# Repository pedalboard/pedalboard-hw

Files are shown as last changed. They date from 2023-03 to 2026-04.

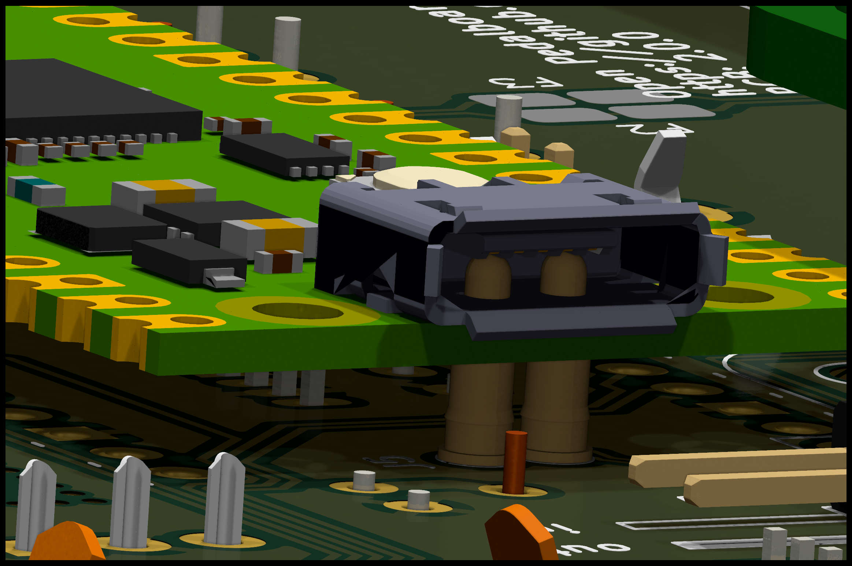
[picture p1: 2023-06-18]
img/pico-usb.png

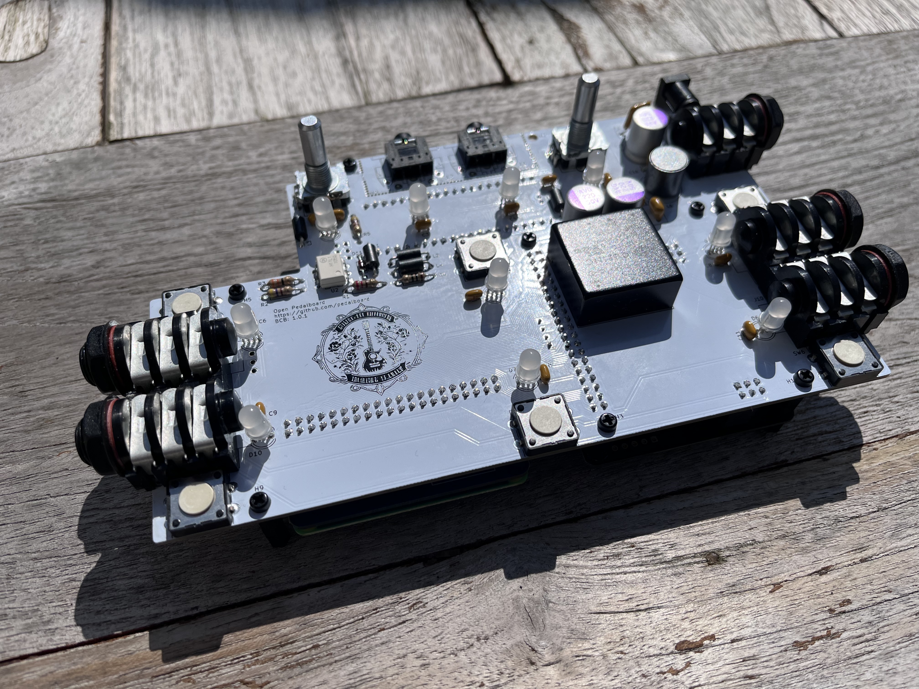
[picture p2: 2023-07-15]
img/prototype.jpeg

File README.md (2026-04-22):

# Open Pedalboard Mainboard

Mainboard for processing audio and/or MIDI data on a pedalboard.

**[Documentation →](https://pedalboard.github.io/pedalboard-hw/latest/)**

PCB 3D Render

## Design Goals

- Modular: MIDI-only or combined MIDI + audio
- Raspberry Pi CM4/CM5 for audio processing (< 2ms latency)
- RP-2040 MIDI controller with independent firmware
- Maker friendly: common components, existing modules
- Flat design: 30mm case height target

## Links

- [Interactive schematic & PCB viewer](https://pedalboard.github.io/pedalboard-hw/latest/board/)
- [Interactive BOM](https://pedalboard.github.io/pedalboard-hw/latest/board/)
- [Downloads & releases](https://pedalboard.github.io/pedalboard-hw/latest/release/)
- [Digi-Key shared list](https://www.digikey.ch/de/mylists/list/DJ3I9KG222)
- [PCBWay manufacturing](https://www.pcbway.com/project/shareproject/Open_Source_Pedalboard_Platform_8e065d23.html)
- [Mechanical parts (3D printable)](https://github.com/pedalboard/pedalboard-case)
- [Release procedure](doc/release-procedure.md)

## License



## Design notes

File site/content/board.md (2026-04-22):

---
title: Board
type: board
weight: 20
---

## Audio Processing

- Raspberry Pi [Compute Module 4](https://www.raspberrypi.com/products/compute-module-4/) or [Compute Module 5](https://www.raspberrypi.com/products/compute-module-5/)
  - Flexible memory options for cost optimisation
  - Optional WiFi
  - Very low latency (~2ms with [ELK Audio OS](https://www.elk.audio/how-elk-audio-os-works))
- [Pedalboard Soundcard](https://pedalboard.github.io/pedalboard-soundcard/latest/) — two channel differential I/O
- or HiFiBerry [DAC+ ADC PRO](https://www.hifiberry.com/shop/boards/hifiberry-dac-adc-pro/) — high quality stereo I/O
- USB-A host + Mini USB device mode (firmware update)

## MIDI and Control Surface

- Raspberry [RP-2040](https://datasheets.raspberrypi.com/rp2040/rp2040-datasheet.pdf) with custom [firmware](https://github.com/pedalboard/pedalboard-midi) (USB or WLAN update)
- 6 foot buttons (push, release, long/short press)
- 2 rotary encoders with push button
- 2 expression pedal inputs
- 8 [RGB LED rings](https://github.com/pedalboard/pedalboard-led-ring) around each foot button
- 2 RGB status LEDs
- STEMMA I2C connector for 2 OLED displays
- I2C EEPROM for config storage
- Flexible MIDI I/O: DIN 5, 3.5mm TRS, header pins, USB MIDI

## Power Supply

- 6–28V DC input (standard pedalboard PSU) with 3A buck converter
- USB powered option for MIDI module
- ORing support between onboard PSU and USB power

## Design Decisions

- **USB 2.0 only** — 480 Mbps is more than sufficient for audio (stereo 24-bit/192kHz ≈ 9 Mbps) and MIDI. USB 3.0 would add cost, routing complexity, and require a 4-layer PCB — with no practical benefit for this use case.
- **2-layer PCB** — keeps manufacturing cost low and the project accessible to makers. USB 2.0 signal integrity is manageable on 2 layers with careful routing and short trace lengths.
- **Dual-processor architecture** — the RP2040 handles MIDI control with instant startup, while the CM4/CM5 runs ELK Audio OS for audio processing. This separation ensures the control surface is always responsive, independent of the audio OS boot state.
- **Modular design** — the board works as a standalone MIDI controller without a CM4 installed, or as a full audio processing platform with CM4/CM5 + soundcard. Common components and existing modules (HiFiBerry, CM4) keep the BOM accessible.

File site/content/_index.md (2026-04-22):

---
title: Overview
weight: 10
---

PCB 3D Render

Mainboard for processing audio and/or MIDI data on a pedalboard.
Modular design supporting MIDI-only or combined MIDI + audio configurations.

## Key Features

- Raspberry Pi CM4/CM5 for audio processing (< 2ms latency with ELK Audio OS)
- RP-2040 MIDI controller with independent firmware and instant startup
- 6 foot buttons (short/long press, push/release) + 2 rotary encoders
- 8 RGB LED ring connectors + 2 OLED display ports
- Flexible MIDI I/O: DIN 5, 3.5mm TRS, USB MIDI, header pins
- 2 expression pedal inputs
- USB-A host + Mini USB device (firmware update)
- 6–28V DC input with 3A buck converter, or USB powered

## Related

- [Sound Card](https://pedalboard.github.io/pedalboard-soundcard/latest/) — I²S audio codec HAT
- [Display Board](https://pedalboard.github.io/pedalboard-display/latest/) — LED rings and OLED displays

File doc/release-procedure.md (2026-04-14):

# How to create a release

The release procedure is not yet fully automated. Please follow below steps:

1. Bump Version

- In Schematic Editor: File -> Page Settings -> Update Issue Date and Revision
  (with export to other sheets)
- In PCB Editor: File -> Page Settings -> Update Issue Date and Revision
- Update CHANGELOG.md (release date)
- Update README.md
  - link the versioned docs.

  ```sh
  sed -i 's#/latest#/vX.Y.Z#g' README.md
  ```

  - link to a (optionally new) DigiKey revision

1. Create a Tag and push it.

   ```sh
   git tag vX.Y.Z
   git push origin vX.Y.Z
   ```

   This triggers the CI to deploy versioned docs to
   `pedalboard.github.io/pedalboard-hw/vX.Y.Z/`.

1. Create a release.

- Generate Release Notes
- Add the relevant content from CHANGELOG.md
- Download the generated_output.zip file from the tagged Action run.
- Add the version to generated_output-x.y.z.zip
- Upload the zip as artifact of the release

1. Bump the version on main to RC1 (as described above)

- Change old version for diff on pedalboard-hw.kibot.yaml (2 lines!)
- Add a new Release in CHANGELOG.md

  ```sh
  sed -i 's#/vX.Y.Z#/latest#g' README.md
  ```

1. Update the OSHWA registration (../../oshwa/README.md)

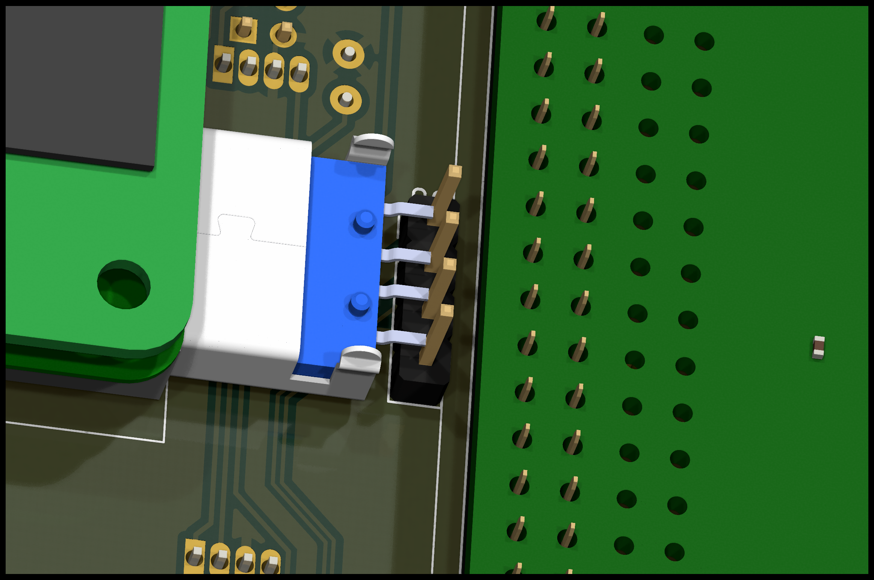
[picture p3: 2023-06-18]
img/cm4-usb.png

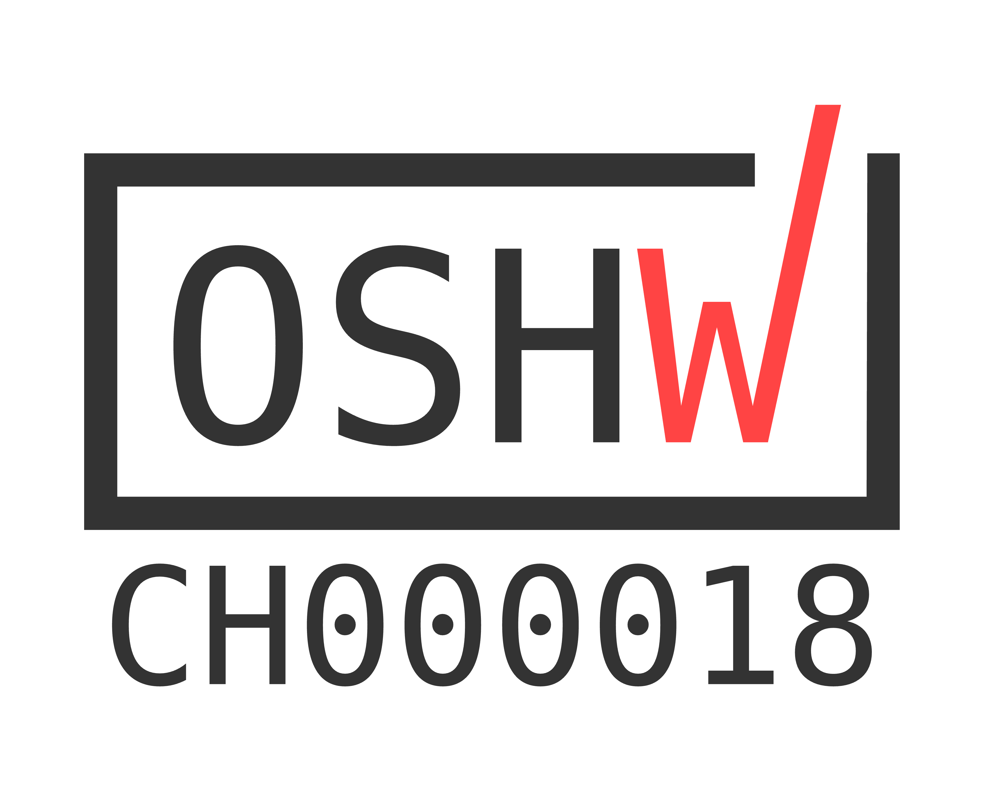
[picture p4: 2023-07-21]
img/certification-mark-CH000018-stacked.png

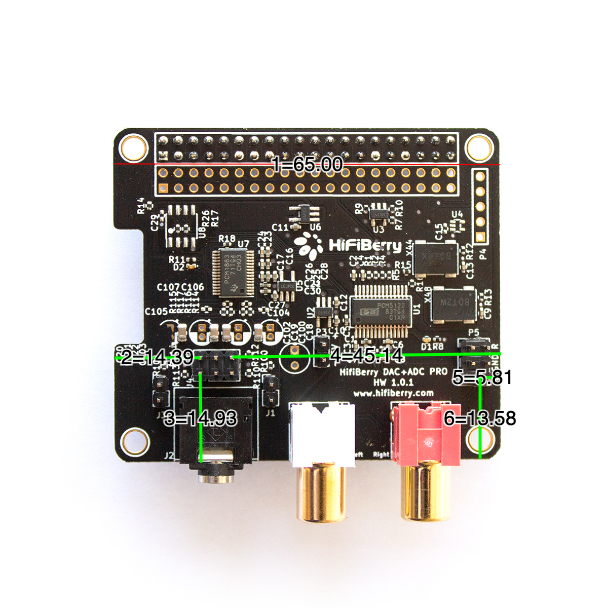
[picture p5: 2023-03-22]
img/dac-adc.png

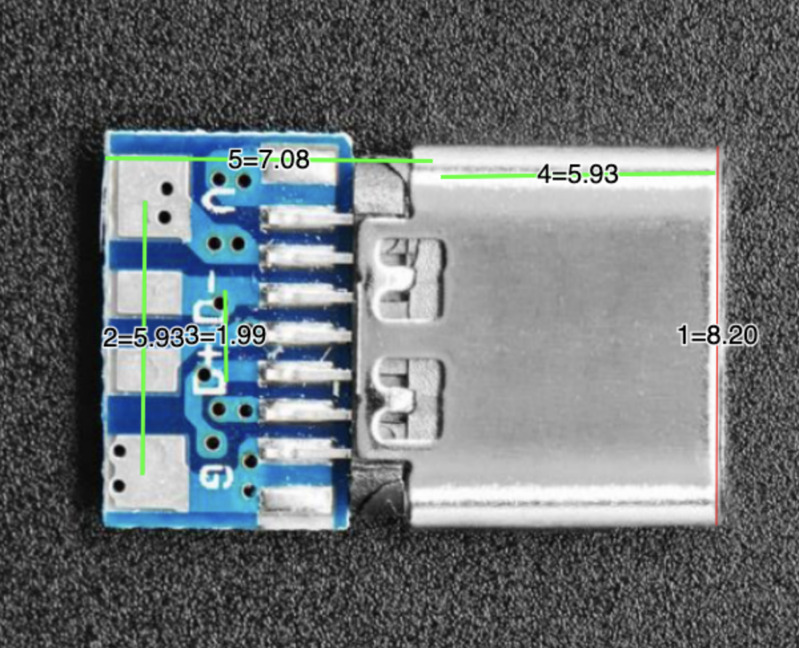
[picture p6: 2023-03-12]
img/usb-c.png

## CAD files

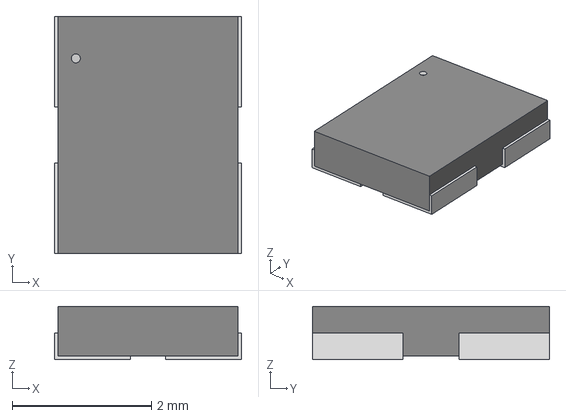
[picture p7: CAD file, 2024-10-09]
3d-models/ABM8-272-T3_ABR.step
2.69 x 3.40 x 0.765 mm

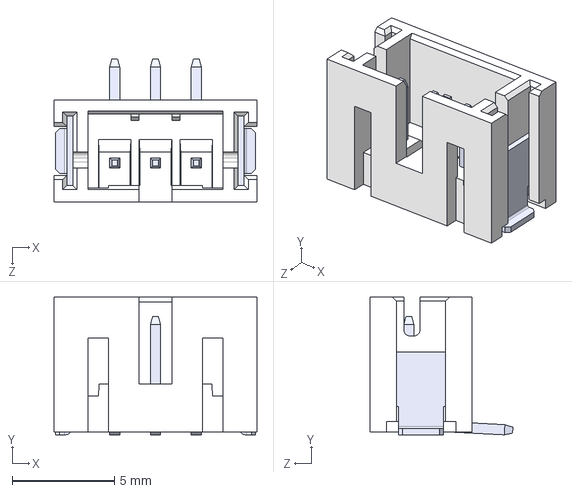
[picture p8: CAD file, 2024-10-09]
3d-models/B3B-PH-SM4-TB(LF)(SN)--3DModel-STEP-269445.STEP
9.95 x 6.75 x 7.00 mm

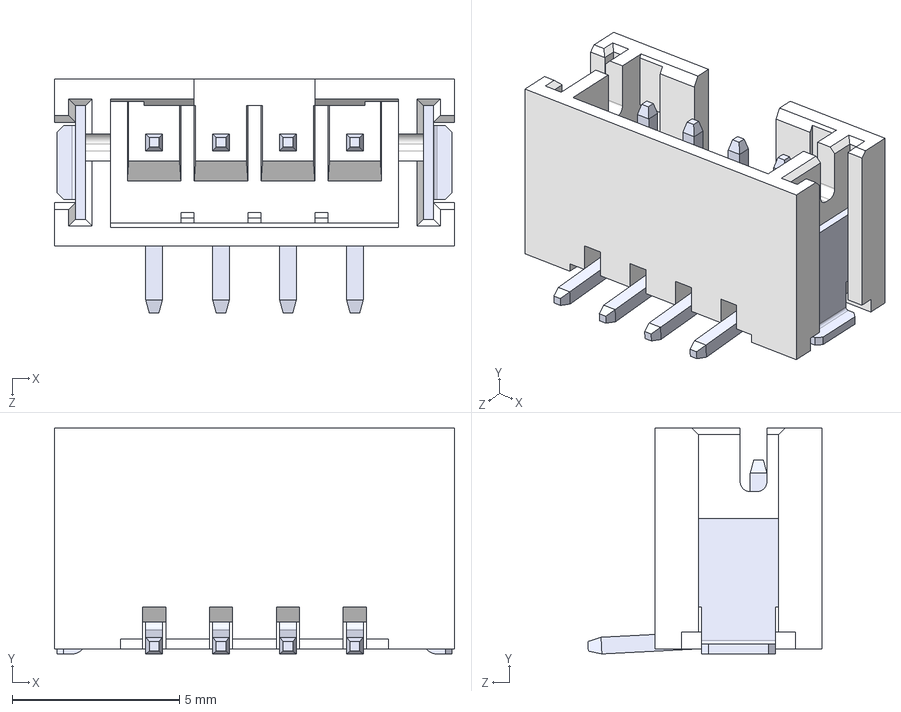
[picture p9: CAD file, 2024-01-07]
3d-models/B4B-PH-SM4-TB (LF)(SN).STEP
12.0 x 6.75 x 7.00 mm

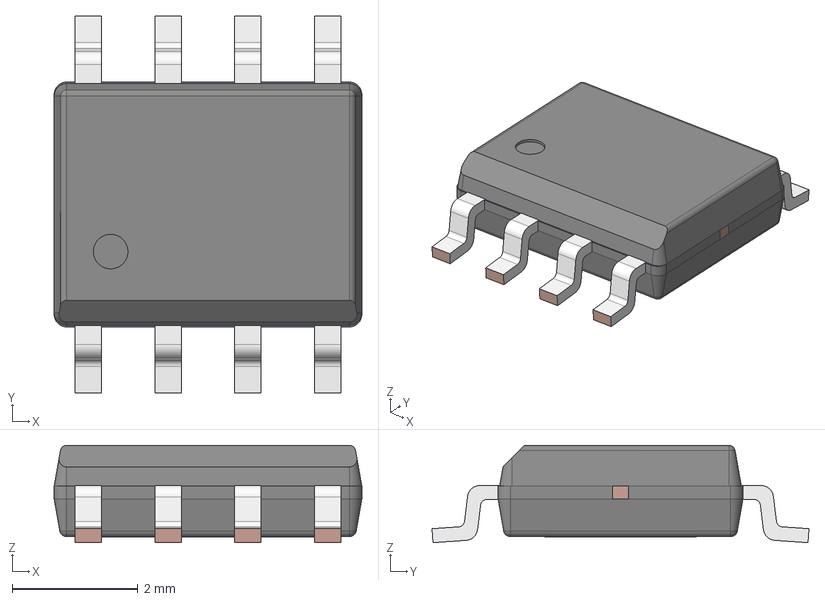
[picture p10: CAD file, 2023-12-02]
3d-models/SO-8EP.STP
4.90 x 6.00 x 1.55 mm
CPD
LDF - outer lead
LDF - 8L-EP

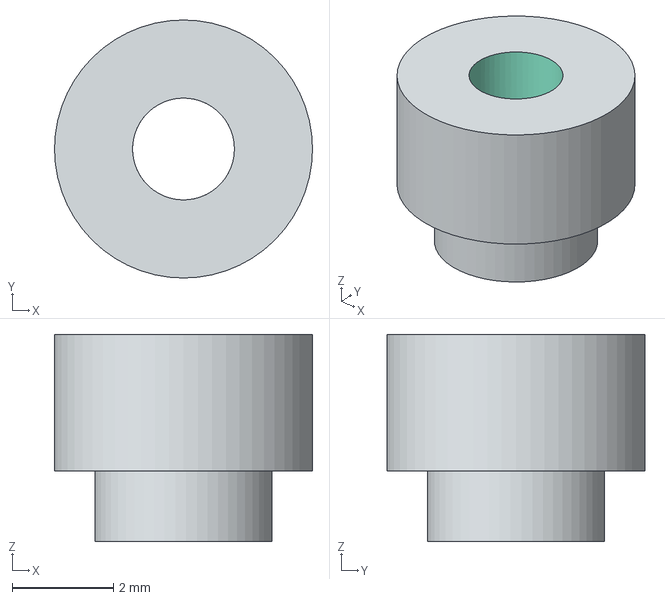
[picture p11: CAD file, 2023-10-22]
3d-models/spacer.stp
5.10 x 5.10 x 4.10 mm

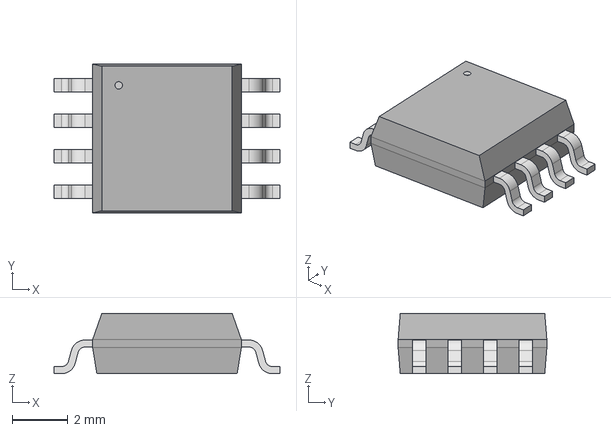
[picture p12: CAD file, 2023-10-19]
3d-models/SOIC_128JVSIQ_WIN.step
8.10 x 5.33 x 2.16 mm

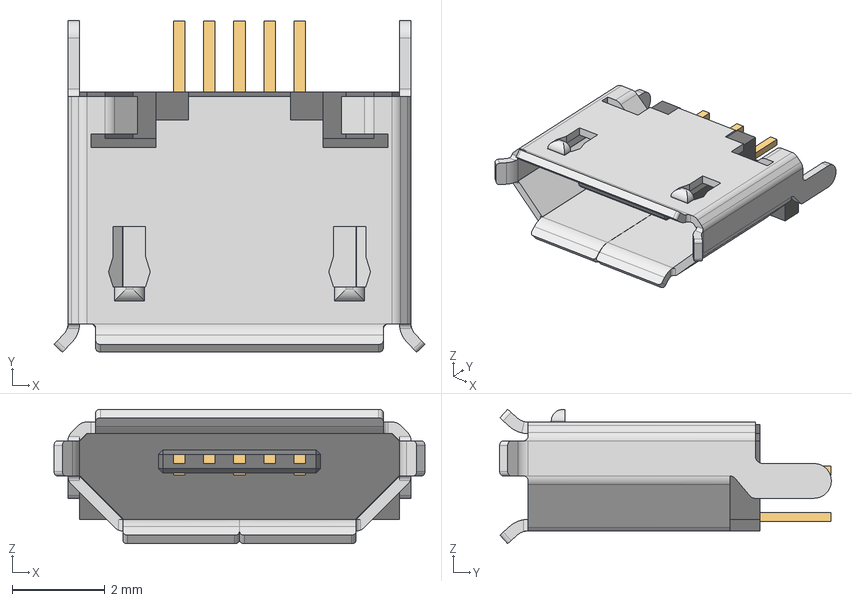
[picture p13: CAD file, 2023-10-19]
3d-models/USB_Micro-B_Wuerth_614105150721.step
8.00 x 7.15 x 2.90 mm
614105150721_Housing
614105150721_Pin1 x 3
614105150721_Pin2 x 2
614105150721_Shielding

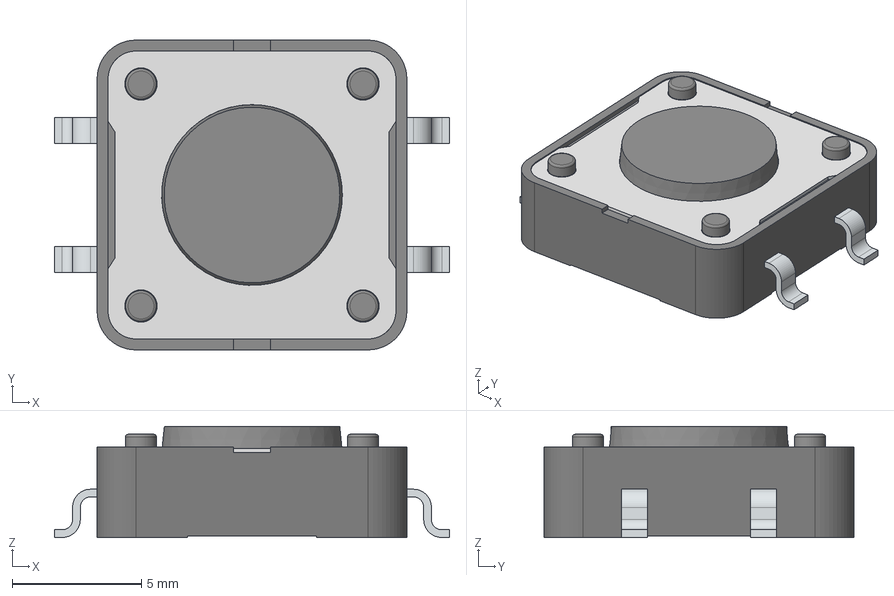
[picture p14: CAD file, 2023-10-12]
3d-models/WE-tact-button.stp
15.3 x 12.0 x 4.30 mm
Contactplates
Stem
Cover
Contact Plate
Frame
Terminal

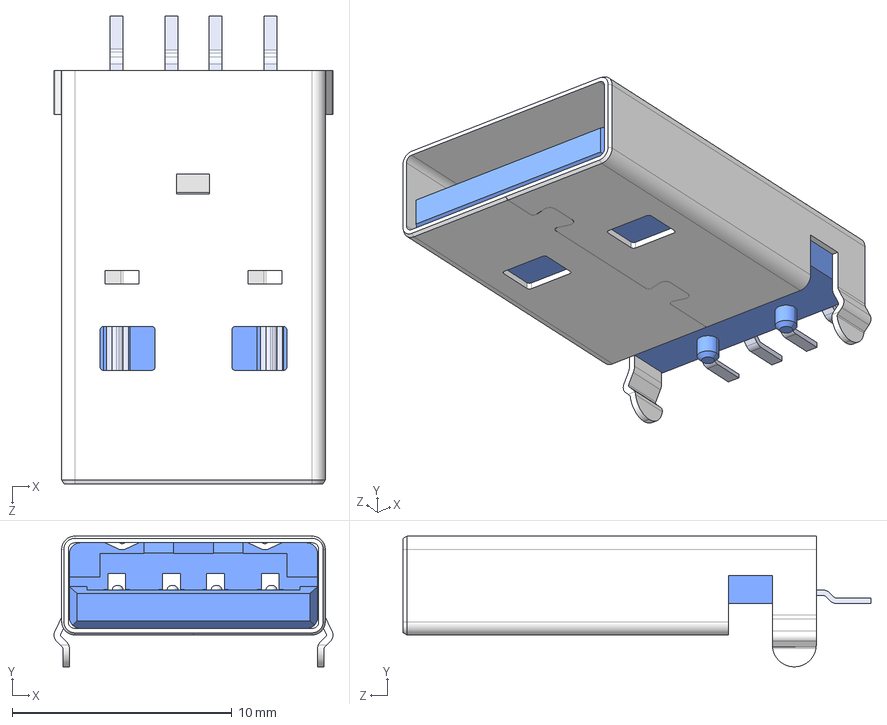
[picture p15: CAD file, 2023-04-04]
3d-models/USB1061-GF-L-A.stp
12.7 x 5.95 x 21.3 mm
USB1061-GF-L-A_PART5
USB1061-GF-L-A_PART4
USB1061-GF-L-A_PART3
USB1061-GF-L-A_PART2
USB1061-GF-L-A_PART1

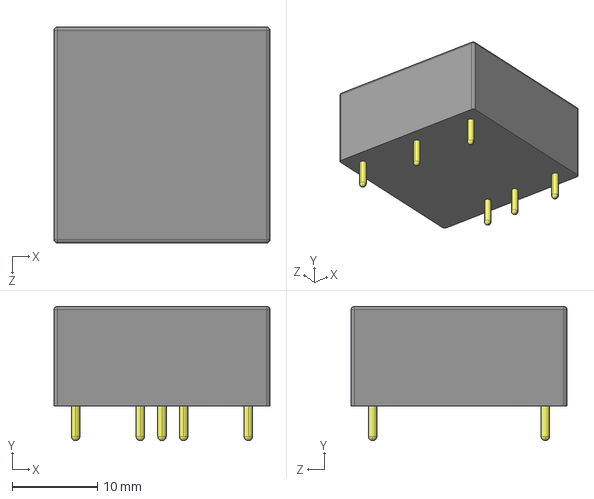
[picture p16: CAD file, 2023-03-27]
3d-models/PDQE15-Q24-S5-D.step
25.4 x 15.8 x 25.4 mm

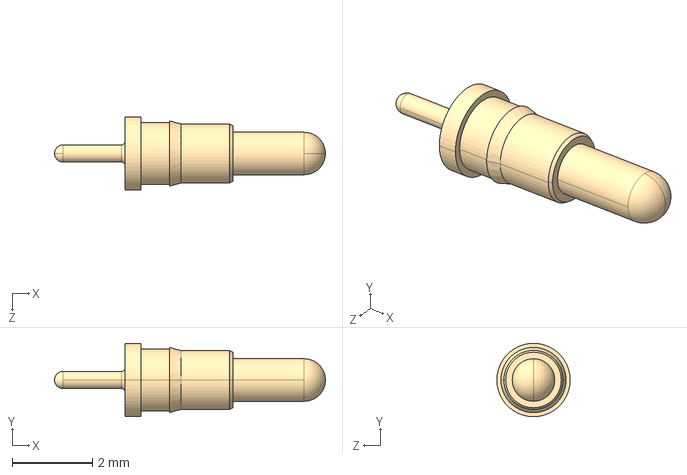
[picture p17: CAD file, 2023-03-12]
3d-models/mill-max-0906-2-15-20-75-14-11-0.step
6.76 x 1.83 x 1.83 mm

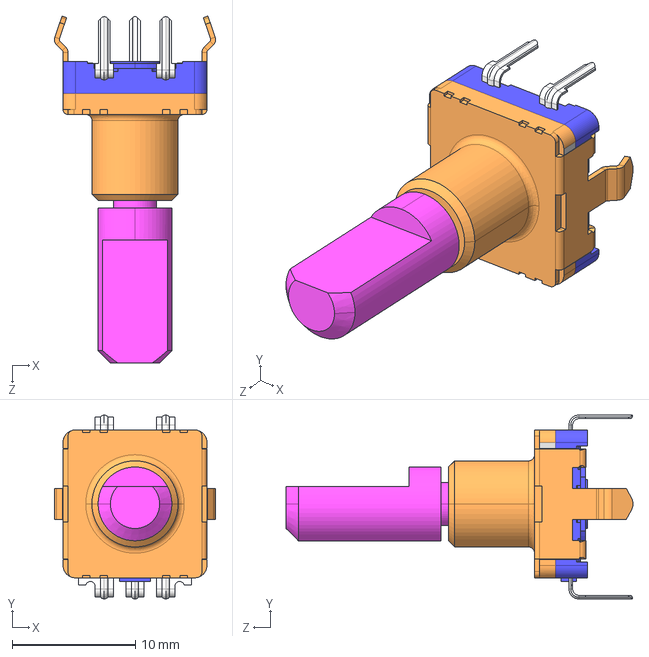
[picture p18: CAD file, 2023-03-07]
3d-models/EC11E-05SW.STEP
13.1 x 15.0 x 28.2 mm

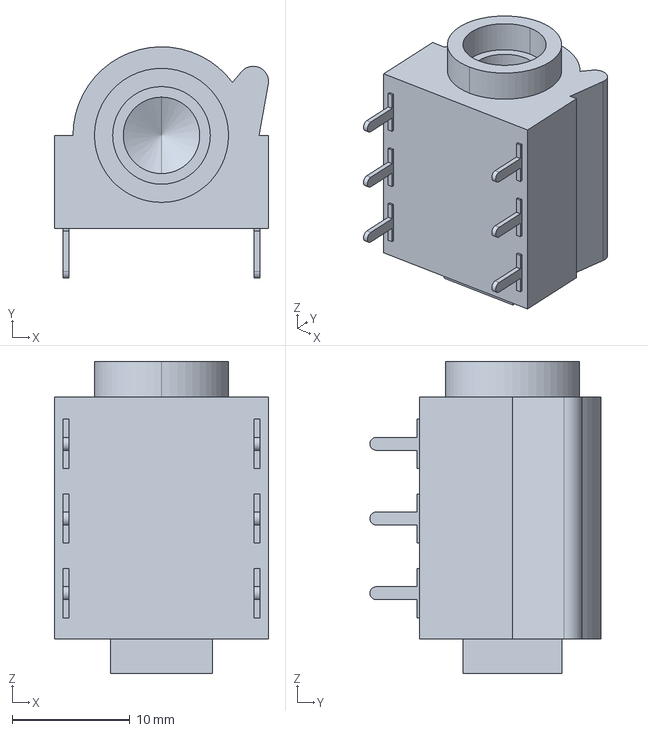
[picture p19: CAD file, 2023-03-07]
3d-models/3-D NMJ6HCD2.stp
18.2 x 19.7 x 26.5 mm

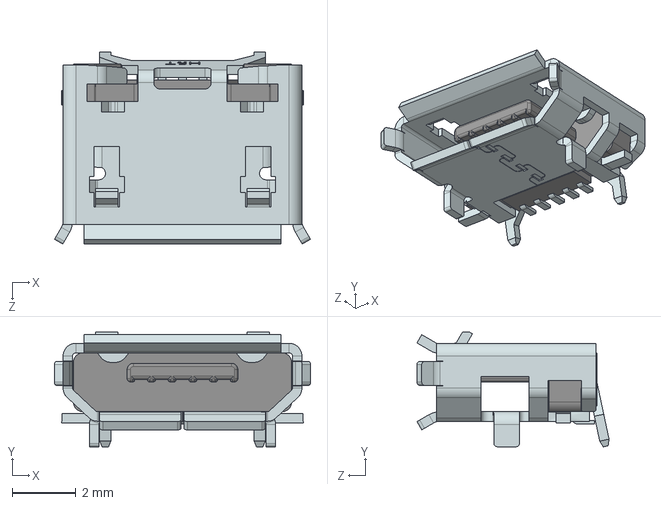
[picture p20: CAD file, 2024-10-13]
3d-models/10103594-0001LF--3DModel-STEP-269445.STEP
8.04 x 3.60 x 6.03 mm

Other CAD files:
3d-models/694106301002 (rev1).stp

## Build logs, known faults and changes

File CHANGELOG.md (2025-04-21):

# Change Log

## TODO

- 2nd USB out
- Input protection
- Bypass USB for MIDI-only controller
- SMD Debug connectors (angled)
- Consistent clearance around mounting holes
- Larger (cheaper) EEPROM

## 4.0.1-RC - -

- Upgrade to KiCad 9
- Tested with CM5

## 4.0.0 - Pedalboard Display and USB - 2024.10.16

### Added

- USB Device in and USB out
- OSHW Symbol
- Silkscreen text for reset/boot switches
- Silkscreen text for MIDI controller inputs
- Git revision is added to schematics and PCB
- Pull-up resistors for I2C bus
- Two more mounting holes (for development)
- 3D model for JST (Stemma)
- One more mounting hole in the center
- User (Test) LED on RP2040
- EEPROM for storing configuration

## Changed

- Change title to Open Pedalboard Mainboard
- Use "knowout" text style for better visibility of connectors
- Swap power symbol to better reflect the terminal connector
- Replace HiFi Berry by pedalboard-soundcard
- Upgrade to KiCad 8
- use smaller XTAL ABM8-272-T3

## Removed

- Fiducials and holes from BOM
- Direct USB connection to RP2040
- LEDs are removed (only 5V adapter left) in favour of the pedalboard-display

## [3.1.1] - Cost Optimisation:  Bug Fixes - 2023-12-05

### Changed

- Increase min. through hole size to 0.3mm

## [3.1.0] - Cost Optimisation:  Bug Fixes - 2023-12-04

### Added

- Stemma connector for displays
- Switch for boot mode and reset of RP2040
- 2 more LED rings for rotary encoders

### Changed

- Increase activity LED resistor to reduce brigtness
- Stemma compatibility for LED out
- Smaller JST PH connectors for MIDI IN/OUT

### Fixed

- Fix USB boot mode bug (wrong wiring)
- Fix CM4 Power LED (invert logic)
- Use power supply based on CM4 IO Board V5
- Decrease stencil sizes (10%) for RP2040- and CM4 connector pads

## [3.0.1] - Cost optimization: Prototype Production Release - 2023-10-20

### Changed

- Increase slot size to (restriction of PCBway)

## [3.0.0] - Cost optimization - 2023-10-19

### Changed

- Use SMD components for MIDI I/O
- Use SMD actuator buttons
- Use concrete PSU implemented with SMD components.
- Use MOS FET instead of diode for reverse polarity protection.
- Use official solder jumper instead of homegrown PCB fuses.
- Increase size of PCB and use 5V zone around the edges.
- Use Connector_JST (XH) for MIDI and LED Ext.
- Directly interface CM4 (Remove CM4 Nano carrier)
- Replace the Pico by directly use RP2040

### Added

- Compatibility with the [Hammond Manufacturing 1590DD](https://www.hammfg.com/files/parts/pdf/1590DD.pdf) case.
- Additional analog (EXP 2) input
- Fidcuials for PnP
- Alternative screw terminal for power input

## [2.1.0] - LED rings - 2023-08-09

### Added

- [Pedalboard LED Ring](https://github.com/pedalboard/pedalboard-led-ring) added.

### Changed

- Use of [SMD Spacers](https://www.digikey.ch/de/products/detail/w%C3%BCrth-elektronik/9774027151R/5320625)
  under the foot buttons for improved mechanical stability.
- The power supply for LEDs from 3.3V to 5V. Allows the use of much larger LED matrices.
- Therefore, a level shifter from 3.3V to 5V had to be added.

## [2.0.0] - 2023-04-24

### Added

- Silkscreen information for connectors to avoid having to refer to the schematics
- Reverse power protection circuit added to Power input.
- Power Raspberry Pico from 5V power supply
- Add internal MIDI connection to free up USB.

### Changed

- BOM: Change LEDs which support 3.3V
- Swap SW A with SW D to cleanup connections

### Fixed

## [1.0.2] - 2023-04-04

### Fixed

- Fix the USB connection between Raspberry Pi and Pico

## [1.0.1] - 2023-03-27

First manufactured version

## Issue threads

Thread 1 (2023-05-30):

Support for LED ring

laenzlinger, 2023-05-30:
The https://github.com/pedalboard/pedalboard-led-ring project provides a nice ring around the foot buttons instead of simple LED.

The protocol is very similar to the single LED but in addition a power supply line needs to be routed and additional pin header are required.

laenzlinger, 2023-06-09:
The routing is already mostly done.

The mounting holes also need to be refactored as a result of the changes now
In addition some sort of 3.3 to 5V adaptation is required since the LED rings are now powered by 5V

laenzlinger, 2023-09-10:
added missing line adapter and spacers. I consider this as done now

Closed 2023-09-10.

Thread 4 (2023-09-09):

LCD support

laenzlinger, 2023-09-09:
Add one?, two? or three? LCDs
Or maybe even 6?

laenzlinger, 2023-12-04:
On V3 i have added a STEMMA output to support small I2C displays

laenzlinger, 2024-01-07:
added pull-up resistors to make it more versatile

laenzlinger, 2024-10-13:
on V4 the displays are on a separate PCB where also all the LED rings are contained.
Two 1.5" 128x128 pixel screens were added.

Closed 2025-04-21.

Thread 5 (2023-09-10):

Fix documentation versioning

laenzlinger, 2023-09-10:
currently the docs are not not avialable for old versions.

laenzlinger, 2023-09-10:
also the release procedure is not yet well documented

laenzlinger, 2023-09-10:
- copied all the released versions into a subdirectory
- the main is pushing into latest

laenzlinger, 2023-09-10:
we should add a version switch to the header if possible

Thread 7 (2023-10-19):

pedalboard soundcard

laenzlinger, 2023-10-19:
Better output drivers (currently the DAC output of the HiFi Berry board are used)
* survive 48V phantom power on output
* Differential outputs (e.g. https://thatcorp.com/datashts/THAT_1606-1646_Datasheet.pdf)
* Output stage https://www.amb.org/audio/
Better input protection

laenzlinger, 2023-12-05:
check out this: https://github.com/zynthian/zynthian-hw/tree/master/ZynADAC

laenzlinger, 2023-12-31:
Implementation ongoing https://github.com/pedalboard/pedalboard-soundcard

laenzlinger, 2024-10-14:
supported on V4

Closed 2025-04-21.

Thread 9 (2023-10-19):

EPROM storage for settings.

laenzlinger, 2023-10-19:

laenzlinger, 2024-01-07:
is it really needed, can't we just store the it in the flash memory?

laenzlinger, 2024-10-14:
added it on PCB, I2C is so small and enough space available

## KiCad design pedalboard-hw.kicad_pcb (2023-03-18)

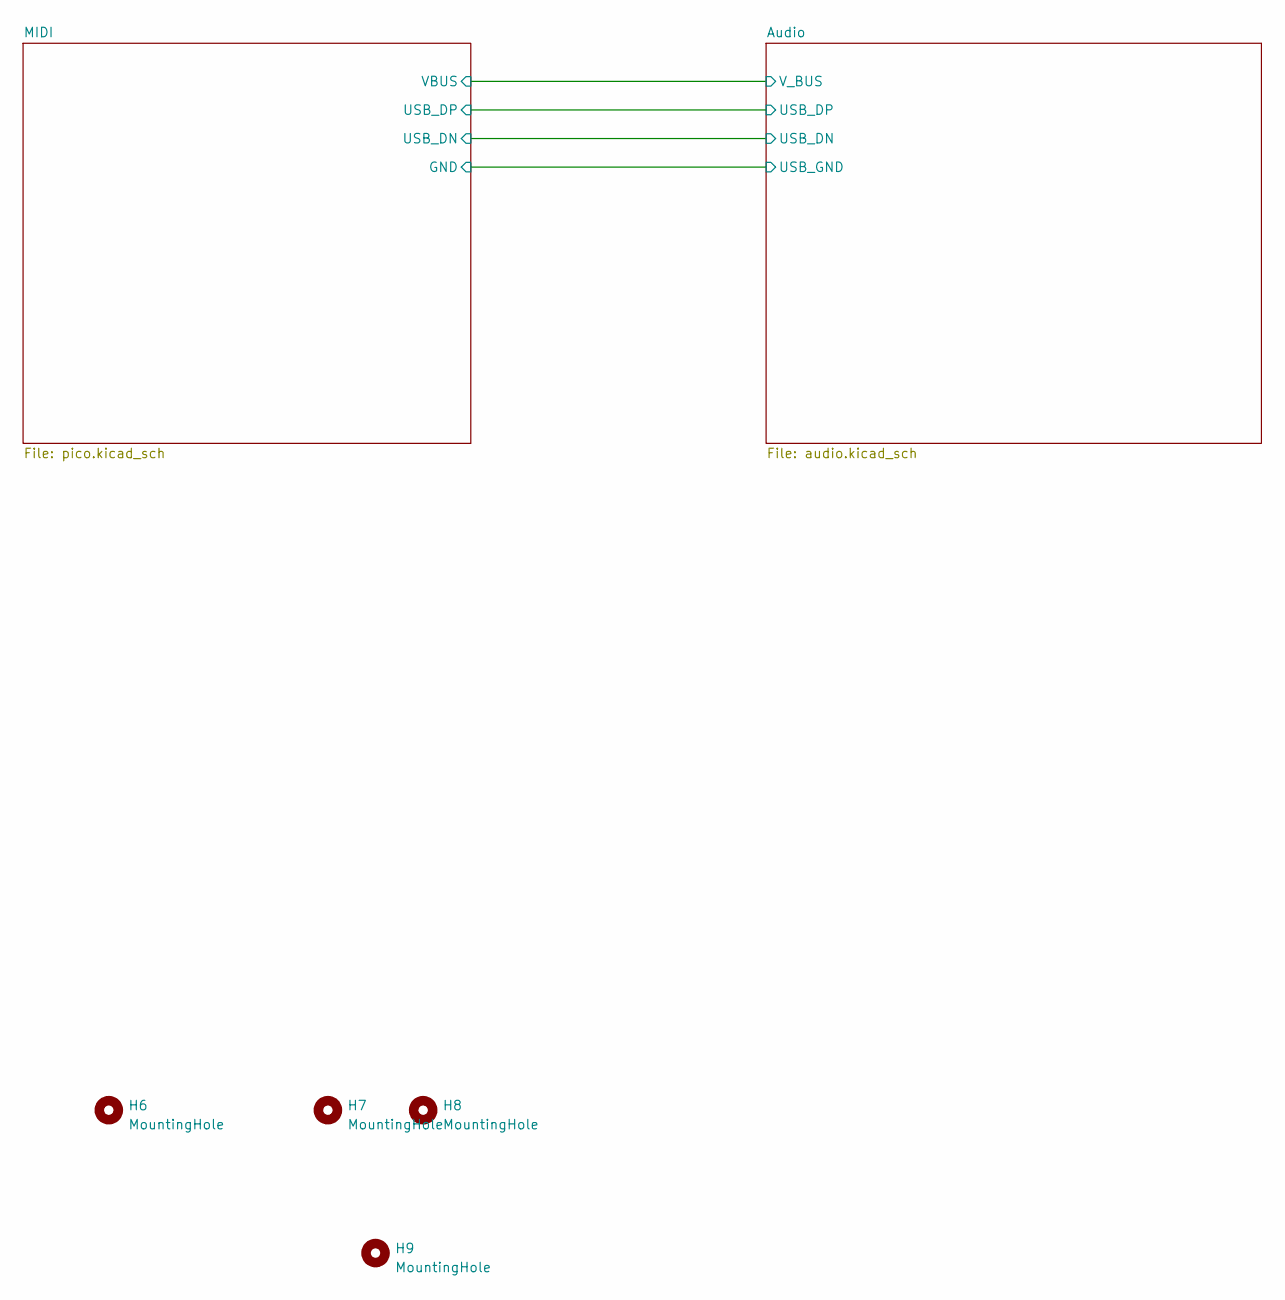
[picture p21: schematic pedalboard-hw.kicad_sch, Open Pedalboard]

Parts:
H6, H7, H8, H9: MountingHole; MountingHole_2.7mm_M2.5_DIN965

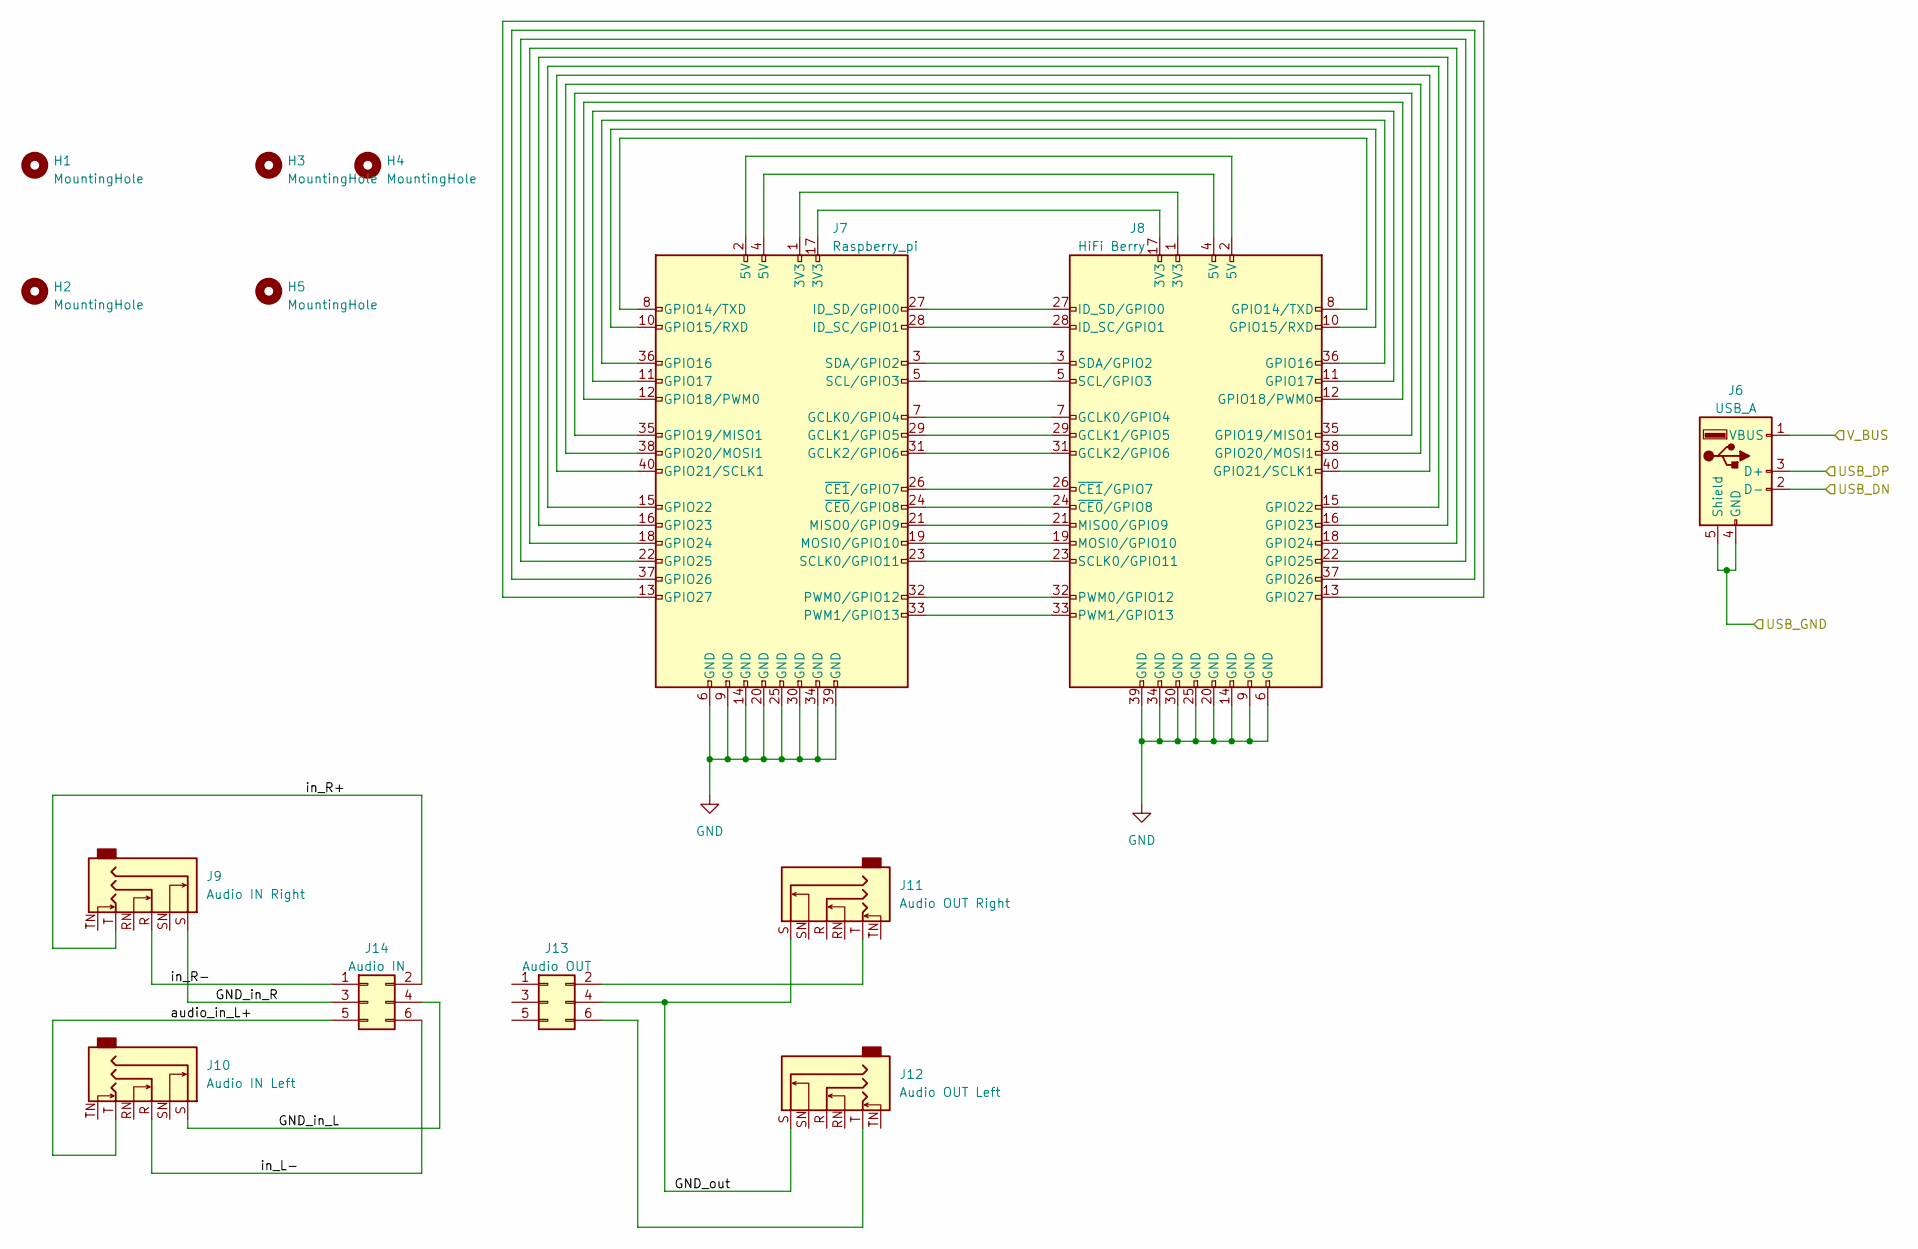
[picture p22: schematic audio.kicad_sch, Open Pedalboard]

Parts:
H1, H2, H3, H4, H5: MountingHole; MountingHole_2.7mm_M2.5_DIN965
J6: USB_A; USB A BCB Male Plug
J7: Raspberry_pi; Raspberry PI Compute Module CM4 Nano A
J8: HiFi Berry; HiFi Berry DAC ADC+
J9: Audio IN Right; Jack_6.35mm_Neutrik_NMJ6HCD2_Horizontal
J10: Audio IN Left; Jack_6.35mm_Neutrik_NMJ6HCD2_Horizontal
J11: Audio OUT Right; Jack_6.35mm_Neutrik_NMJ6HCD2_Horizontal
J12: Audio OUT Left; Jack_6.35mm_Neutrik_NMJ6HCD2_Horizontal
J13: Audio OUT; PinSocket_2x03_P2.54mm_Vertical
J14: Audio IN; PinSocket_2x03_P2.54mm_Vertical

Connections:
/Audio/GND_in_L: J10.S, J14.4
/Audio/GND_in_R: J9.S, J14.3
/Audio/GND_out: J11.S, J12.S, J13.4
/Audio/USB_DN: J6.2 (D-); also elsewhere on the board
/Audio/USB_DP: J6.3 (D+); also elsewhere on the board
/Audio/V_BUS: J6.1 (VBUS); also elsewhere on the board
/Audio/audio_in_L+: J10.T, J14.5
/Audio/in_L-: J10.R, J14.6
/Audio/in_R+: J9.T, J14.2
/Audio/in_R-: J9.R, J14.1
GND: J6.4 (GND), J6.5 (Shield), J7.6 (GND), J7.9 (GND), J7.14 (GND), J7.20 (GND), J7.25 (GND), J7.30 (GND), J7.34 (GND), J7.39 (GND), J8.6 (GND), J8.9 (GND), J8.14 (GND), J8.20 (GND), J8.25 (GND), J8.30 (GND), J8.34 (GND), J8.39 (GND); also elsewhere on the board
unnamed: J7.1 (3V3), J8.1 (3V3)
unnamed: J7.17 (3V3), J8.17 (3V3)
unnamed: J7.2 (5V), J8.2 (5V)
unnamed: J7.4 (5V), J8.4 (5V)
unnamed: J7.7 (GCLK0/GPIO4), J8.7 (GCLK0/GPIO4)
unnamed: J7.29 (GCLK1/GPIO5), J8.29 (GCLK1/GPIO5)
unnamed: J7.31 (GCLK2/GPIO6), J8.31 (GCLK2/GPIO6)
unnamed: J7.8 (GPIO14/TXD), J8.8 (GPIO14/TXD)
unnamed: J7.10 (GPIO15/RXD), J8.10 (GPIO15/RXD)
unnamed: J7.36 (GPIO16), J8.36 (GPIO16)
unnamed: J7.11 (GPIO17), J8.11 (GPIO17)
unnamed: J7.12 (GPIO18/PWM0), J8.12 (GPIO18/PWM0)
unnamed: J7.35 (GPIO19/MISO1), J8.35 (GPIO19/MISO1)
unnamed: J7.38 (GPIO20/MOSI1), J8.38 (GPIO20/MOSI1)
unnamed: J7.40 (GPIO21/SCLK1), J8.40 (GPIO21/SCLK1)
unnamed: J7.15 (GPIO22), J8.15 (GPIO22)
unnamed: J7.16 (GPIO23), J8.16 (GPIO23)
unnamed: J7.18 (GPIO24), J8.18 (GPIO24)
unnamed: J7.22 (GPIO25), J8.22 (GPIO25)
unnamed: J7.37 (GPIO26), J8.37 (GPIO26)
unnamed: J7.13 (GPIO27), J8.13 (GPIO27)
unnamed: J7.28 (ID_SC/GPIO1), J8.28 (ID_SC/GPIO1)
unnamed: J7.27 (ID_SD/GPIO0), J8.27 (ID_SD/GPIO0)
unnamed: J7.21 (MISO0/GPIO9), J8.21 (MISO0/GPIO9)
unnamed: J7.19 (MOSI0/GPIO10), J8.19 (MOSI0/GPIO10)
unnamed: J7.32 (PWM0/GPIO12), J8.32 (PWM0/GPIO12)
unnamed: J7.33 (PWM1/GPIO13), J8.33 (PWM1/GPIO13)
unnamed: J7.23 (SCLK0/GPIO11), J8.23 (SCLK0/GPIO11)
unnamed: J7.5 (SCL/GPIO3), J8.5 (SCL/GPIO3)
unnamed: J7.3 (SDA/GPIO2), J8.3 (SDA/GPIO2)
unnamed: J7.24 (~CE0/GPIO8), J8.24 (~CE0/GPIO8)
unnamed: J7.26 (~CE1/GPIO7), J8.26 (~CE1/GPIO7)
unnamed: J11.T, J13.2
unnamed: J12.T, J13.6

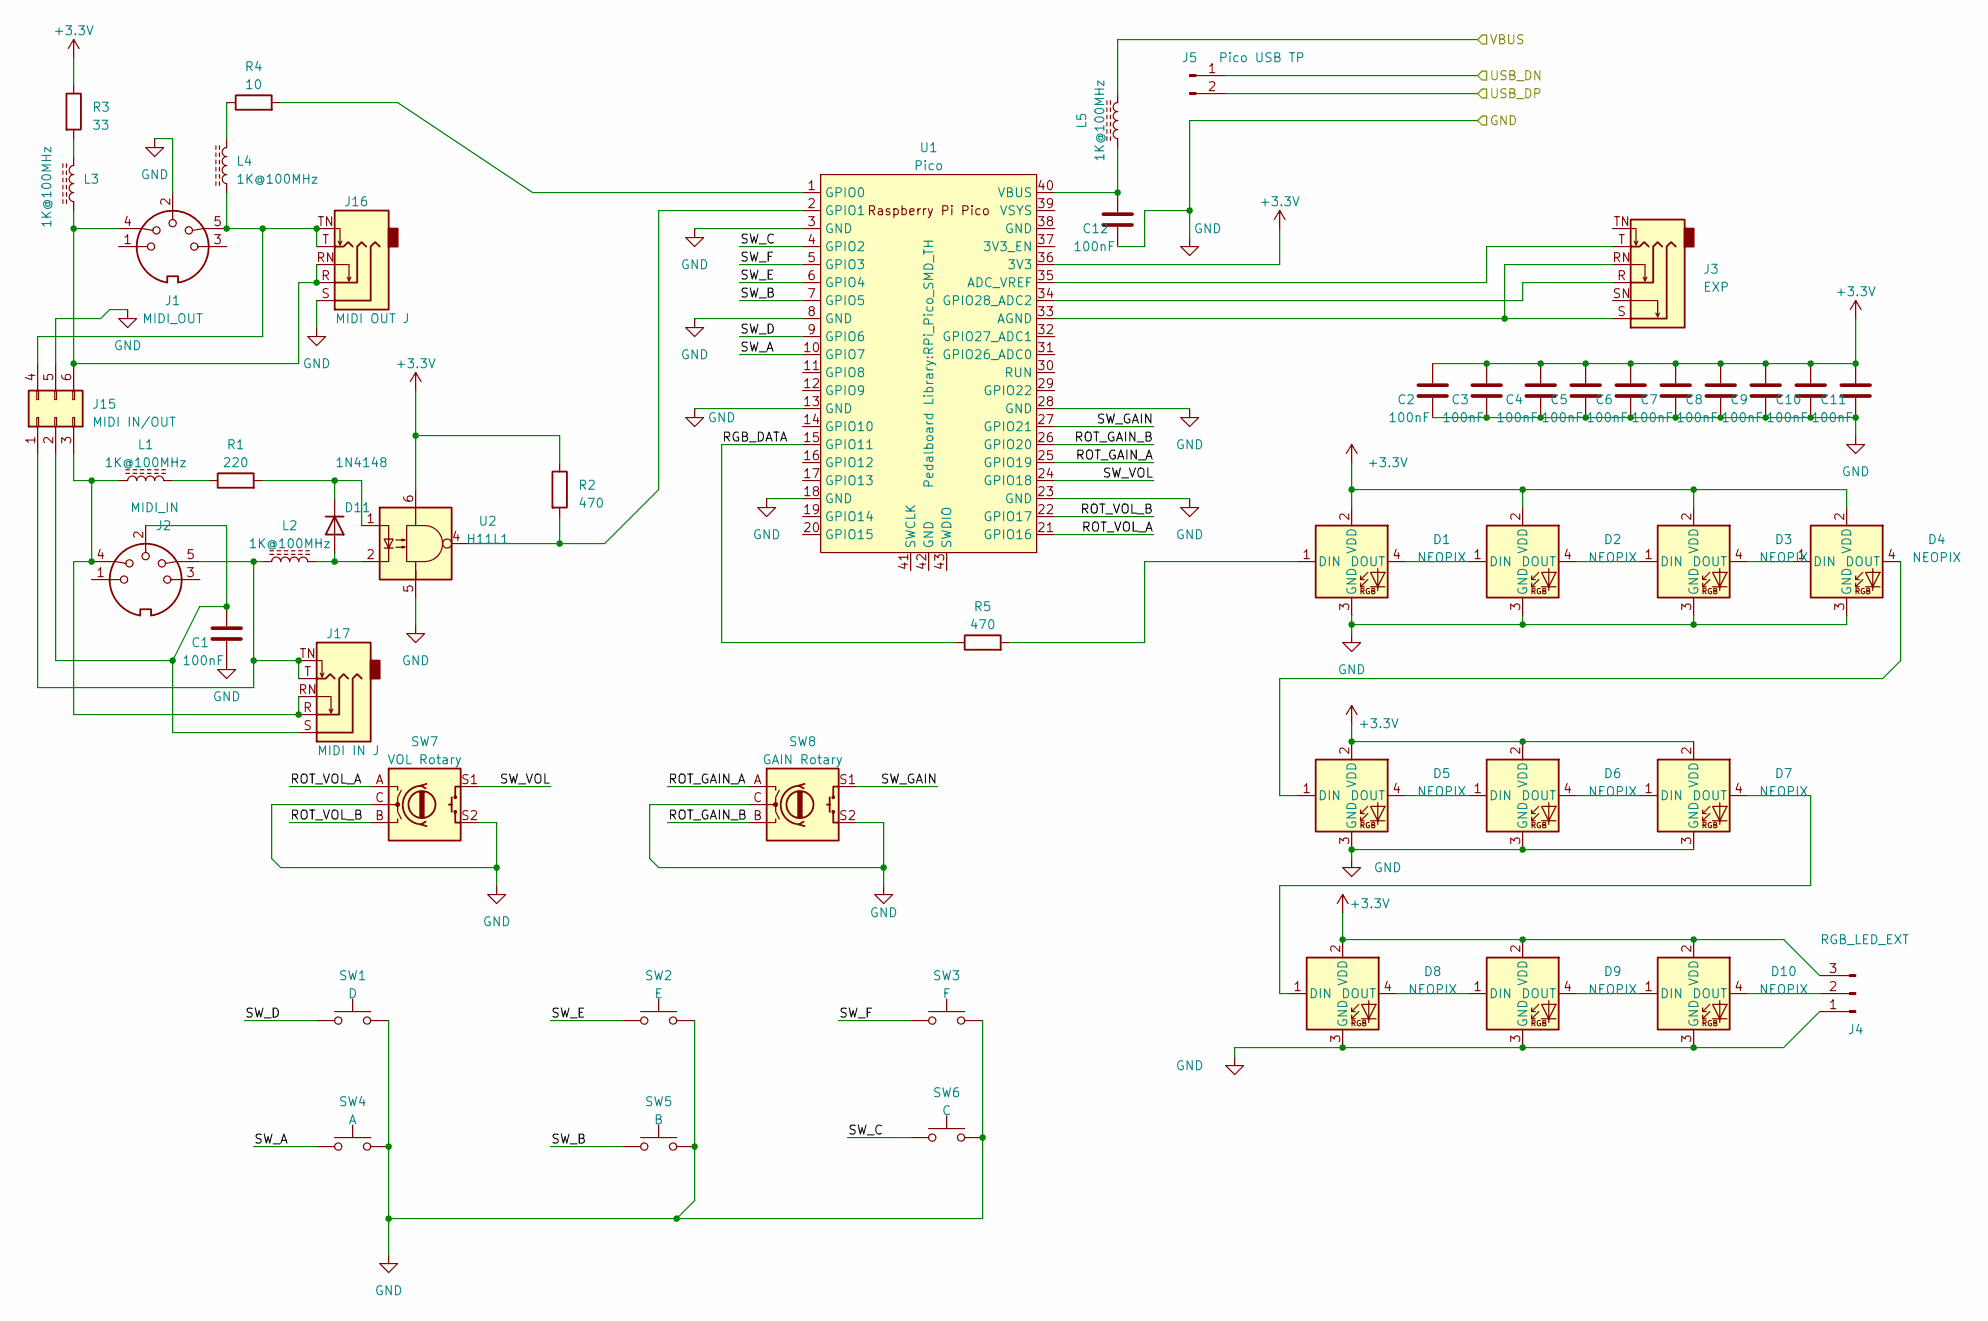
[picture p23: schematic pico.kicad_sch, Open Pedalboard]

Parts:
C1, C2, C3, C4, C5, C6, C7, C8, C9, C10, C11, C12: 100nF; C_Disc_D3.0mm_W1.6mm_P2.50mm
D1, D2, D3, D4, D5, D6, D7, D8, D9, D10: NEOPIX; LED_D5.0mm-NeoPixel
D11: 1N4148; D_DO-35_SOD27_P7.62mm_Horizontal
J1: MIDI_OUT; CP-2350
J2: MIDI_IN; CP-2350
J3: EXP; Jack_6.35mm_Neutrik_NMJ6HCD2_Horizontal
J4: RGB_LED_EXT; PinHeader_1x03_P2.54mm_Horizontal
J5: Pico USB TP; Spring_Loaded_Pins_2mm
J15: MIDI IN/OUT; PinHeader_2x03_P2.54mm_Horizontal
J16: MIDI OUT J; Jack_3.5mm_CUI_SJ1-3525N_Horizontal
J17: MIDI IN J; Jack_3.5mm_CUI_SJ1-3525N_Horizontal
L1, L2, L3, L4, L5: 1K@100MHz; L_Axial_L6.6mm_D2.7mm_P10.16mm_Horizontal_Vishay_IM-2
R1: 220; R_Axial_DIN0207_L6.3mm_D2.5mm_P10.16mm_Horizontal
R2, R5: 470; R_Axial_DIN0207_L6.3mm_D2.5mm_P10.16mm_Horizontal
R3: 33; R_Axial_DIN0207_L6.3mm_D2.5mm_P10.16mm_Horizontal
R4: 10; R_Axial_DIN0207_L6.3mm_D2.5mm_P10.16mm_Horizontal
SW1: D; SW_PUSH-12mm_Wuerth-430476085716
SW2: E; SW_PUSH-12mm_Wuerth-430476085716
SW3: F; SW_PUSH-12mm_Wuerth-430476085716
SW4: A; SW_PUSH-12mm_Wuerth-430476085716
SW5: B; SW_PUSH-12mm_Wuerth-430476085716
SW6: C; SW_PUSH-12mm_Wuerth-430476085716
SW7: VOL Rotary; RotaryEncoder_Alps_EC11E-Switch_Vertical_H20mm_CircularMoun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
SW8: GAIN Rotary; RotaryEncoder_Alps_EC11E-Switch_Vertical_H20mm_CircularMoun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
U1: Pico; RPi_Pico_SMD_TH
U2: H11L1; DIP-6_W7.62mm_LongPads

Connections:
+3.3V: C2.1, C3.1, C4.1, C5.1, C6.1, C7.1, C8.1, C9.1, C10.1, C11.1, D1.2 (VDD), D2.2 (VDD), D3.2 (VDD), D4.2 (VDD), D5.2 (VDD), D6.2 (VDD), D7.2 (VDD), D8.2 (VDD), D9.2 (VDD), D10.2 (VDD), J4.3, R2.1, R3.1, U1.36 (3V3), U2.6
/Audio/USB_DN: J5.1; also elsewhere on the board
/Audio/USB_DP: J5.2; also elsewhere on the board
/Audio/V_BUS: L5.2; also elsewhere on the board
/MIDI/RGB_DATA: R5.1, U1.15 (GPIO11)
/MIDI/ROT_GAIN_A: SW8.A, U1.25 (GPIO19)
/MIDI/ROT_GAIN_B: SW8.B, U1.26 (GPIO20)
/MIDI/ROT_VOL_A: SW7.A, U1.21 (GPIO16)
/MIDI/ROT_VOL_B: SW7.B, U1.22 (GPIO17)
/MIDI/SW_A: SW4.1, U1.10 (GPIO7)
/MIDI/SW_B: SW5.1, U1.7 (GPIO5)
/MIDI/SW_C: SW6.1, U1.4 (GPIO2)
/MIDI/SW_D: SW1.1, U1.9 (GPIO6)
/MIDI/SW_E: SW2.1, U1.6 (GPIO4)
/MIDI/SW_F: SW3.1, U1.5 (GPIO3)
/MIDI/SW_GAIN: SW8.S1, U1.27 (GPIO21)
/MIDI/SW_VOL: SW7.S1, U1.24 (GPIO18)
GND: C1.2, C2.2, C3.2, C4.2, C5.2, C6.2, C7.2, C8.2, C9.2, C10.2, C11.2, C12.2, D1.3 (GND), D2.3 (GND), D3.3 (GND), D4.3 (GND), D5.3 (GND), D6.3 (GND), D7.3 (GND), D8.3 (GND), D9.3 (GND), D10.3 (GND), J1.2, J4.1, J15.5, J16.S, SW1.2, SW2.2, SW3.2, SW4.2, SW5.2, SW6.2, SW7.C, SW7.S2, SW8.C, SW8.S2, U1.3 (GND), U1.8 (GND), U1.13 (GND), U1.18 (GND), U1.23 (GND), U1.28 (GND), U2.5; also elsewhere on the board
unnamed: D1.1 (DIN), R5.2
unnamed: D1.4 (DOUT), D2.1 (DIN)
unnamed: D2.4 (DOUT), D3.1 (DIN)
unnamed: D3.4 (DOUT), D4.1 (DIN)
unnamed: D4.4 (DOUT), D5.1 (DIN)
unnamed: D5.4 (DOUT), D6.1 (DIN)
unnamed: D6.4 (DOUT), D7.1 (DIN)
unnamed: D7.4 (DOUT), D8.1 (DIN)
unnamed: D8.4 (DOUT), D9.1 (DIN)
unnamed: D9.4 (DOUT), D10.1 (DIN)
unnamed: D10.4 (DOUT), J4.2
unnamed: D11.2 (A), L2.2, U2.2
unnamed: D11.1 (K), R1.2, U2.1
unnamed: J2.5, J15.1, J17.T, J17.TN, L2.1
unnamed: C1.1, J2.2, J15.2, J17.S
unnamed: J2.4, J15.3, J17.R, J17.RN, L1.1
unnamed: J1.5, J15.4, J16.T, J16.TN, L4.1
unnamed: J1.4, J15.6, J16.R, J16.RN, L3.1
unnamed: L1.2, R1.1
unnamed: L3.2, R3.2
unnamed: L4.2, R4.1
unnamed: J3.T, U1.35 (ADC_VREF)
unnamed: J3.RN, J3.S, U1.33 (AGND)
unnamed: R4.2, U1.1 (GPIO0)
unnamed: R2.2, U1.2 (GPIO1), U2.4
unnamed: J3.R, U1.34 (GPIO28_ADC2)
unnamed: C12.1, L5.1, U1.40 (VBUS)

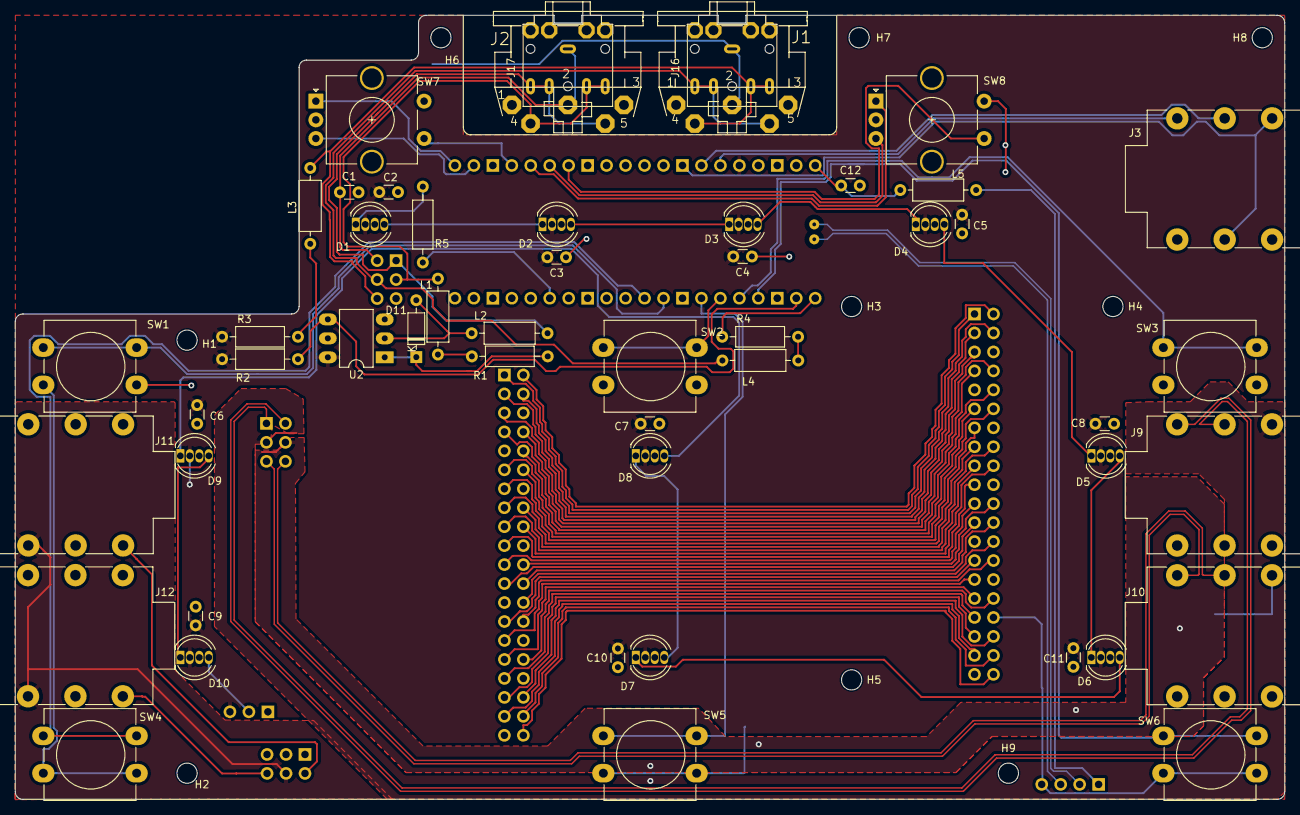
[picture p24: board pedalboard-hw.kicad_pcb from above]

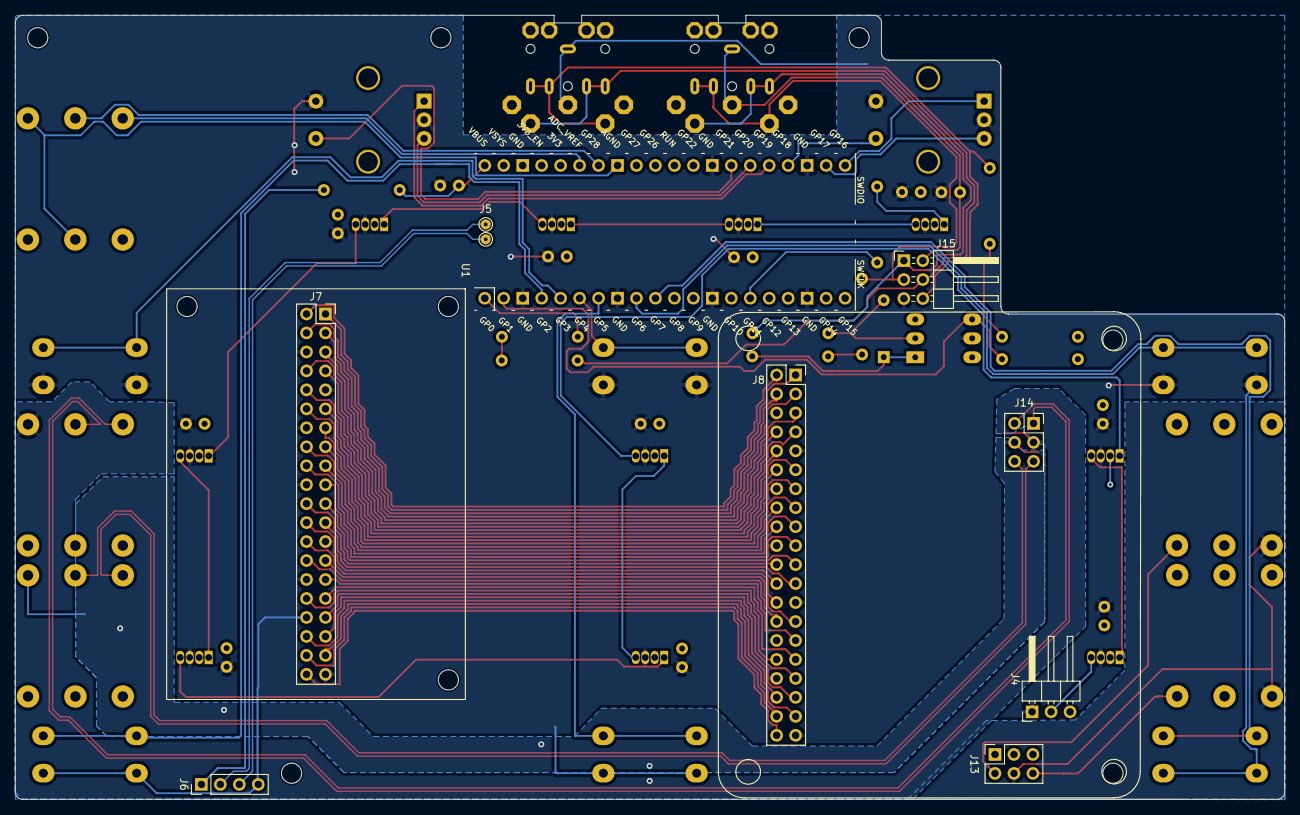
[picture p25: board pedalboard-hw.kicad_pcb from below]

Board: 2 copper layers, 170.0 x 105.0 mm, 69 parts (8 on the bottom side), 86 nets.

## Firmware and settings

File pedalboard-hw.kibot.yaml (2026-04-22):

kibot:
  version: 1

global:
  kicad_dnp_applies_to_3D: true
  filters:
    - number: 1007
    - number: 1015
    - number: 58

import:
  - file: Elecrow
  - file: FusionPCB
  - file: JLCPCB
  - file: MacroFab_XYRS
  - file: PCB2Blender_2_1
  - file: PCBWay

preflight:
  erc:
    enabled: true
  drc:
    enabled: true
  check_zone_fills: true
  set_text_variables:
    name: GIT_HASH
    command: git rev-parse --short HEAD

outputs:
  - name: basic_blender_export
    comment: 3D renders (Blender)
    type: blender_export
    dir: 3D
    options:
      pcb3d: _PCB2Blender_2_1
      add_default_light: false
      light:
        - name: sun
          type: SUN
          energy: 3
        - name: fill
          type: POINT
          pos_x: 'size*3'
          pos_y: '-size*3'
          pos_z: 'size*4'
          energy: 0
      render_options:
        resolution_x: 2560
        resolution_y: 1440
        samples: 20
        transparent_background: true
        auto_crop: true
      outputs:
        - type: render
      point_of_view:
        - rotate_x: 30
          rotate_z: -20
          file_id: _1_top
        - rotate_x: 210
          rotate_z: -20
          file_id: _2_bottom
  - name: basic_boardview
    comment: Board View export
    type: boardview
    dir: Assembly
  - name: generic_bom_html
    comment: Generic Bill of Materials in HTML format
    type: bom
    dir: BoM/Generic
    options:
      format: HTML
      count_smd_tht: true
  - name: generic_bom_csv
    comment: Generic Bill of Materials in CSV format
    type: bom
    dir: BoM/Generic
    options:
      format: CSV
      count_smd_tht: true
  - name: generic_bom_hrtxt
    comment: Generic Bill of Materials in HRTXT format
    type: bom
    dir: BoM/Generic
    options:
      format: HRTXT
      hrtxt:
        separator: "|"
      count_smd_tht: true
  - name: generic_bom_tsv
    comment: Generic Bill of Materials in TSV format
    type: bom
    dir: BoM/Generic
    options:
      format: TSV
      count_smd_tht: true
  - name: generic_bom_xml
    comment: Generic Bill of Materials in XML format
    type: bom
    dir: BoM/Generic
    options:
      format: XML
      count_smd_tht: true
  - name: generic_bom_xlsx
    comment: Generic Bill of Materials in XLSX format
    type: bom
    dir: BoM/Generic
    options:
      format: XLSX
      count_smd_tht: true
  - name: positional_bom_html
    comment: Positional Bill of Materials in HTML format
    type: bom
    dir: BoM/Positional
    options:
      format: HTML
      columns: &id001
        - Row
        - Description
        - Part
        - Part Lib
        - References
        - Value
        - Footprint
        - Footprint Lib
        - Quantity Per PCB
        - Build Quantity
        - Status
        - Datasheet
        - Supplier
        - Sheetpath
        - Source BoM
        - Footprint X
        - Footprint Y
        - Footprint Rot
        - Footprint Side
        - Footprint Type
        - Footprint Populate
        - Footprint X-Size
        - Footprint Y-Size
      count_smd_tht: true
      html:
        style: modern-red
  - name: positional_bom_xlsx
    comment: Positional Bill of Materials in XLSX format
    type: bom
    dir: BoM/Positional
    options:
      format: XLSX
      columns: *id001
      count_smd_tht: true
      xlsx:
        style: modern-red
  - name: costs_bom_xlsx
    comment: Costs Bill of Materials in XLSX format
    type: bom
    dir: BoM/Costs
    options:
      format: XLSX
      count_smd_tht: true
      xlsx:
        style: modern-green
        kicost: true
        specs: true
        kicost_api_disable: KitSpace
      pre_transform: _kicost_rename
  - name: macrofab_xyrs
    comment: Pick and place file, XYRS style
    extends: _macrofab_xyrs
    type: bom
    options:
      columns:
        - field: References
          name: Designator
        - field: Footprint X
          name: X-Loc
        - field: Footprint Y
          name: Y-Loc
        - field: Footprint Rot
          name: Rotation
        - field: Footprint Side
          name: Side
        - field: Footprint Type
          name: Type
        - field: Footprint X-Size
          name: X-Size
        - field: Footprint Y-Size
          name: Y-Size
        - field: Value
        - field: Footprint
        - field: Footprint Populate
          name: Populate
    dir: Position
  - name: basic_diff_pcb
    comment: PCB diff between the last two changes
    type: diff
    dir: diff
    layers:
      - layer: F.Cu
        suffix: F_Cu
        description: Front copper
      - layer: B.Cu
        suffix: B_Cu
        description: Bottom copper
      - layer: B.Silkscreen
        suffix: B_Silkscreen
        description: Bottom silkscreen (artwork)
      - layer: F.Silkscreen
        suffix: F_Silkscreen
        description: Front silkscreen (artwork)
      - layer: B.Mask
        suffix: B_Mask
        description: Bottom soldermask (negative)
      - layer: F.Mask
        suffix: F_Mask
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

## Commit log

2023-02-27 Some very first experiments with KiCad
    [inputs.kicad_sch, leds.kicad_sch, pedalboard-hw.kicad_pcb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]
2023-02-28 Add Midi & Rotary buttons
    [inputs.kicad_sch, leds.kicad_sch, pedalboard-hw.kicad_sch]
2023-02-28 Move leds to pico page
    [pedalboard-hw.kicad_sch, pico.kicad_sch]
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2023-02-28 Add connector for LED extension
    [pedalboard-hw.kicad_sch, pico.kicad_sch]
2023-02-28 Fix pico footprint
    [pico.kicad_sch]
2023-03-01 Define Edge Cuts and change footprints of buttons, add headers
    [pedalboard-hw.kicad_pcb, pico.kicad_sch]
2023-03-01 Initial placement of components
    [pedalboard-hw.kicad_pcb]
2023-03-01 Move controllers and LEDs to the correct place:
    [pedalboard-hw.kicad_pcb]
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2023-03-01 use sockets for HiFiBerry
    [audio.kicad_sch, pedalboard-hw.kicad_pcb, pico.kicad_sch]
2023-03-02 HiFiBerry locations (best guess)
    [pedalboard-hw.kicad_pcb]
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2023-03-06 Add 3d Model for CM4 carrier
    [pedalboard-hw.kicad_pcb]
2023-03-06 Place the CM4 carrier
    [pedalboard-hw.kicad_pcb]
2023-03-06 Add CM4 3d model
    [pedalboard-hw.kicad_pcb]
2023-03-06 MIDI: Add Ferrite Beads
    [pico.kicad_sch]
2023-03-06 MIDI: Set Footprints for MIDI sheets
    [pico.kicad_sch]
2023-03-06 Add Footprint for MIDI IN/OUT
    [pico.kicad_sch]
2023-03-06 Add new Footprints from schema
    [pedalboard-hw.kicad_pcb]
2023-03-06 Remove edge cuts for MIDI sockets
    [pedalboard-hw.kicad_pcb]
2023-03-06 Move Pi socket silkscreen to bottom
    [pedalboard-hw.kicad_pcb]
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2023-03-06 Replace midi output by single connector
    [pico.kicad_sch]
2023-03-06 Fix Audio Connectors
    [audio.kicad_sch]
2023-03-07 Connect the USB between the processors
    [audio.kicad_sch, pedalboard-hw.kicad_pcb, pedalboard-hw.kicad_sch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]
2023-03-07 Add 3d model for Jack connectors
    [3-D NMJ6HCD2.stp, pedalboard-hw.kicad_pcb]
2023-03-07 Fix Jack Connectors (Rotation)
    [pedalboard-hw.kicad_pcb]
2023-03-07 3d model for rotary encoders
    [EC11E-05SW.STEP, pedalboard-hw.kicad_pcb]
2023-03-07 Add first 3d preview images
    [430476085716_Download_STP_430476085716_rev1.stp, pedalboard-hw.kicad_pcb]
2023-03-07 Use smaller bead with 3d model
    [pedalboard-hw.kicad_pcb, pico.kicad_sch]
2023-03-07 Replace NeoPixel with TH version
    [pedalboard-hw.kicad_pcb, pico.kicad_sch]
2023-03-07 Fix NEO Pixel footprint assignment
    [pedalboard-hw.kicad_pcb, pico.kicad_sch]
2023-03-07 Improve Neopixel circuit by adding capacitors
    [pedalboard-hw.kicad_pcb, pico.kicad_sch]
2023-03-07 Raise the Pico Hight since there are now parts below
    [pedalboard-hw.kicad_pcb]
2023-03-07 Move around some stuff before cutting out pcb
    [pedalboard-hw.kicad_pcb]
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2023-03-07 Add Audio 3.5mm Midi Connectors
    [pedalboard-hw.kicad_pcb, pico.kicad_sch]
2023-03-07 Add Audio 3.5mm Midi Connectors (3d model)
    [pedalboard-hw.kicad_pcb]
2023-03-07 Auto place midi circuit
    [pedalboard-hw.kicad_pcb]
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2023-03-11 Swap Gain and Vol
    [pico.kicad_sch]
2023-03-11 Revert "Swap Gain and Vol"
    This reverts commit eff2662083f133e78864251a31f115c395281ae7.
    [pico.kicad_sch]
2023-03-11 Swap Pins for Gain and Vol
    [pico.kicad_sch]
2023-03-11 Revert "Swap Pins for Gain and Vol"
    This reverts commit bde537fef4603a1fb51c66edd46a3ab8782a39ff.
    [pico.kicad_sch]
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2023-03-11 Small routing fixes
    [pedalboard-hw.kicad_pcb]
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2023-03-11 Fixing connection issues
    [pedalboard-hw.kicad_pcb]
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2023-03-11 All connection issues fixed
    [pedalboard-hw.kicad_pcb]
2023-03-11 Fix errors by using correct prio
    [pedalboard-hw.kicad_pcb]
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2023-03-11 Remove outline of 3.5mm jack (Fixes Board outline)
    [pedalboard-hw.kicad_pcb]
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2023-03-11 Fix footprint of 3.5mm plug
    [pedalboard-hw.kicad_pcb]
2023-03-11 Fix curtyard overlap
    [pedalboard-hw.kicad_pcb]
2023-03-11 Fix warnings (100 left)
    [pedalboard-hw.kicad_pcb]
2023-03-11 Fix overlaps (76 Warnings left)
    [pedalboard-hw.kicad_pcb]
2023-03-11 Fix silkscreen warnings
    [pedalboard-hw.kicad_pcb]
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2023-03-12 Add a power decoupling circuit for the Pico
    [audio.kicad_sch, pedalboard-hw.kicad_pcb, pico.kicad_sch]
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2023-03-12 Fix error (C too close to switch)
    [pedalboard-hw.kicad_pcb]
2023-03-12 Fix error (Bridge Ground Zones)
    [pedalboard-hw.kicad_pcb]
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2023-03-12 Use 100Ohm @ 100MHz (1k are just too big)
    [pedalboard-hw.kicad_pcb, pico.kicad_sch]
2023-03-12 Exclude some of the errors
    [pedalboard-hw.kicad_pcb]
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2023-03-12 Increase Clearance for Pogo Pins
    [pedalboard-hw.kicad_pcb]
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2023-03-13 Fix CRC errors (connect 3.3V panes)
    [pedalboard-hw.kicad_pcb]
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2023-03-14 Fix BOM
    [audio.kicad_sch, pedalboard-hw.csv, pico.kicad_sch]
2023-03-14 Fix MIDI DIN 5 component
    [pedalboard-hw.csv, pico.kicad_sch]
2023-03-14 Fix LEDs in BOM
    [pedalboard-hw.csv, pico.kicad_sch]
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2023-03-14 Fix mounting hole
    [pedalboard-hw.kicad_pcb]
2023-03-14 Remove mounting hole where it does not make sense
    [pedalboard-hw.kicad_pcb]
2023-03-14 Add the audio mounting holes to the schema
    [audio.kicad_sch, pedalboard-hw.kicad_pcb]
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2023-03-15 Free up real estate to move midi circuit
    [pedalboard-hw.kicad_pcb]
2023-03-15 Free up more real estate to move midi circuit
    [pedalboard-hw.kicad_pcb]
2023-03-15 More real estate for moving the MIDI circuit
    [pedalboard-hw.kicad_pcb]
2023-03-15 Move the midi circuit out away from the HiFiBerry area
    [pedalboard-hw.kicad_pcb]
2023-03-15 Fix errors (by also changing the RPI pico footprint
    [pedalboard-hw.kicad_pcb]
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2023-03-15 More fixes
    [pedalboard-hw.kicad_pcb]
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2023-03-18 Cut out more real estate for connectors and plugs
    [pedalboard-hw.kicad_pcb]
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2023-03-18 Fix layer of dimensions
    [pedalboard-hw.kicad_pcb]
2023-03-18 Fix Jack component
    [audio.kicad_sch, pedalboard-hw.csv, pico.kicad_sch]
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2023-03-19 Improve Audio in Routing (since now there is more space under the HIFI berry
    [audio.kicad_sch]
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2023-03-19 Remove debug pins from RPI pico schema, since we don't use them
    [pico.kicad_sch]
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2023-03-19 Add footprint for MIDI plugs in own library
    [pico.kicad_sch]
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2023-03-22 Revert HiFi Berry so that it can be mounted without modification
    [audio.kicad_sch, pedalboard-hw.kicad_sch]
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2023-03-22 Fix Logo on back side and add version to silkscreen
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2023-03-25 Fix some warnings in the BOM generator
2023-03-25 Fix some pcb errors
    [pico.kicad_sch]
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2023-03-25 Replace footprints of switches to project level library
2023-03-25 Fix path to 3d model of pico
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2023-03-26 Connect the audio input to gnd when not plugged in
    [audio.kicad_sch]
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2023-03-26 Revert Zoom to 10
    [pedalboard-hw.kibot.yaml]
2023-03-26 Labels for thei RPI pins used by HifiBerry
    [audio.kicad_sch]
2023-03-26 Add stereo detector pins on in and output
    [audio.kicad_sch]
2023-03-26 Try to fix 3d zoom
    [pedalboard-hw.kibot.yaml]
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2023-03-27 Fix some kibot warnings
    [pico.kicad_sch, psu.kicad_sch]
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2023-03-27 Add missing GND connection
    [pico.kicad_sch]
2023-03-27 Try to make kibot happy with better values for L
    [pico.kicad_sch]
2023-03-27 Fix DRC errors (remove a unused 5V symbol)
    [audio.kicad_sch, pico.kicad_sch]
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2023-03-27 Fix the definition of the main power jack as power ouput
    [psu.kicad_sch]
2023-03-27 Fix more ERC errors
    [audio.kicad_sch, pico.kicad_sch, psu.kicad_sch]
2023-03-27 Fix all ERC errors
    [audio.kicad_sch, pico.kicad_sch, psu.kicad_sch]
2023-03-27 Add missing BOM values
    [audio.kicad_sch, pico.kicad_sch, psu.kicad_sch]
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2023-03-28 Add missing footprint description
    [psu.kicad_sch]
2023-03-28 Fix BOM and improve outline of Midi Schematic
    [audio.kicad_sch, pico.kicad_sch]
2023-04-04 Bugfixes on first PCB build:
    - Mixed up USB plug
    - Filtered VBUS must also be power line
    [pico.kicad_sch]
2023-04-04 Fix 3D model of USB connector
    [USB1061-GF-L-A.stp]
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2023-04-04 Fix Location of D1 text on Silkscreen
2023-04-04 Fix location of C texts in Silkscreen
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2023-04-07 Add reverse power protection circuit
    [psu.kicad_sch]
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2023-04-07 Fix ERC
    [audio.kicad_sch, pico.kicad_sch, psu.kicad_sch]
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2023-04-15 Connect internal MIDI, swap connections for switches
    [audio.kicad_sch, pedalboard-hw.kicad_sch, pico.kicad_sch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]
2023-04-15 Change net name to make it more consistent
    [audio.kicad_sch, pico.kicad_sch, psu.kicad_sch]
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2023-06-11 Only populate the LED rings (incl 3D mocel)
    [leds.kicad_sch]
2023-06-11 Fix old version ref
    [pedalboard-hw.kibot.yaml]
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2023-09-10 Level adapter from 3.3V to 5V for LEDs
    [leds.kicad_sch]
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2023-09-10 Replace Schotky Diode with SMD part
    [pico.kicad_sch]
2023-09-10 Replace buttons with SMD part
    [pico.kicad_sch]
2023-09-10 Replace LEDs with SMD part
    [leds.kicad_sch]
2023-09-10 Replace Fuse with SMD part
    [psu.kicad_sch]
2023-09-10 Replace reverse power diode with MOSFET
    [leds.kicad_sch, psu.kicad_sch]
2023-09-10 Replace incuctor for PSU with SMD component
    [psu.kicad_sch]
2023-09-10 Replace capacitors for PSU with SMD components
    [leds.kicad_sch, psu.kicad_sch]
2023-09-10 Fix ERC errors
    [leds.kicad_sch, psu.kicad_sch]
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2023-10-10 use solder jumpers instead of own nasty fuses
    [audio.kicad_sch, pico.kicad_sch]
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2023-10-12 Refactor LED ring rotations to avoid overlap with other footprints
2023-10-12 Fix button footprint (was THT instead of SMD)
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2023-10-12 Fix power input connector (schematic)
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2023-10-13 Fix LED locations
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2023-10-16 Fix 3d models for 200 pin connector
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2023-10-18 Squashed commit of the following:
    commit 3fa4ca4d3c5ea62d251efd6d8a974a8ccaef8e6e
    Author: Christof Laenzlinger <6319634+laenzlinger@users.noreply.github.com>
    Date: Thu Oct 19 01:43:32 2023 +0200
    Cleanup Silkscreen
    commit 95b56afabf9d984d42b570e7dd0e9dc0995e2e0a
    Author: Christof Laenzlinger <6319634+laenzlinger@users.noreply.github.com>
    Date: Thu Oct 19 01:37:16 2023 +0200
    Fix ERC and DRC
    commit bd76d654c6e0ce2e50bc4bd0303c6b77f3cbeef5
    Author: Christof Laenzlinger <6319634+laenzlinger@users.noreply.github.com>
    Date: Thu Oct 19 01:10:46 2023 +0200
    Fix ERC and DRC
    commit a0cad1f8b96ac3ca8d87a02e21e40253cfdda0dd
    Author: Christof Laenzlinger <6319634+laenzlinger@users.nore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
    [pedalboard-hw.kicad_sch, pico.kicad_sch, psu.kicad_sch]
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2023-10-22 Fix Datasheet for Shotky diode
    [psu.kicad_sch]
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2023-10-22 Fix Supplier Link for 1uF capacitor
    [pico.kicad_sch]
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2023-10-22 Fix Supplier Link for 22uF capacitor
    [psu.kicad_sch]
2023-10-22 Fix Supplier Link for 0.1uF capacitor
    [leds.kicad_sch, pico.kicad_sch, psu.kicad_sch]
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2023-10-23 Fix datasheet urls
    [pico.kicad_sch, psu.kicad_sch]
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2023-11-21 Fix USB Boot mode bug
    [pico.kicad_sch]
2023-11-26 Invert CM4 power LED
    [audio.kicad_sch]
2023-11-29 Use PSU design based on CM4IO V5 board
    [leds.kicad_sch, pico.kicad_sch, psu.kicad_sch]
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2023-12-02 Add tactile button for reset (RP2040)
    [pico.kicad_sch]
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2023-12-02 Fix buttons
    [pico.kicad_sch]
2023-12-02 Fix 3d model of buck converter
    [psu.kicad_sch]
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2023-12-03 Fix position of new LED rings
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2023-12-04 Use JST PH consistently (since its also used by STEMMA
    [pico.kicad_sch]
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2023-12-04 Revert "Soldermask color to white"
    This reverts commit 0fb851f5ae9f513fe24f1a630c152fa3989f80b8.
    [pedalboard-hw.kibot.yaml]
2023-12-04 Revert "try some new colors for 3d view"
    This reverts commit f849c1d0f29300a9a1679607f3b9d7c0fa9f5f5f.
    [pedalboard-hw.kibot.yaml]
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2023-12-04 Revert "All 3d images in white"
    This reverts commit cf1a680a94822b390be0284eadb46a3dacae5ada.
    [pedalboard-hw.kibot.yaml]
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2023-12-27 Prepare for next release, add OSHW symbol and cleanup BOM
    [audio.kicad_sch, connect.kicad_sch, leds.kicad_sch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]
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2024-01-07 Revert the power silkscreen symbol
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2024-01-07 Add git commit to schema sheets and PCB sheet
    [audio.kicad_sch, connect.kicad_sch, leds.kicad_sch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]
2024-01-07 Try drc exclusion workaround
    [pedalboard-hw.kibot.yaml]
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2024-01-07 Replace HiFi Berry by pedalboard-soundcard
    [audio.kicad_sch]
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2024-01-07 Show screw terminal instead on 3d view (DNP for jack barrel)
    [psu.kicad_sch]
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2024-10-09 Fix stencil generator
    [B3B-PH-SM4-TB(LF)(SN)--3DModel-STEP-269445.STEP]
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2024-10-12 First routing. Still many issues
    [audio.kicad_sch, connect.kicad_sch, pedalboard-hw.kicad_sch]
2024-10-12 Fix all errors
    [connect.kicad_sch]
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2024-10-15 Fix typo and ESC errors
    [connect.kicad_sch]
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2024-10-15 Fix Datasheet for XTAL
    [pico.kicad_sch]
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2024-10-16 Fix symbol warnings
    [audio.kicad_sch, connect.kicad_sch, leds.kicad_sch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]
2024-10-16 Fix warngings
    [audio.kicad_sch, leds.kicad_sch, psu.kicad_sch]
2024-10-16 Fix new errors
    [psu.kicad_sch]
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2024-10-16 Add missing symbol to library
    [psu.kicad_sch]
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2024-10-16 Fix duplicate net warning
    [audio.kicad_sch]
2024-10-16 Fix last warning
    [connect.kicad_sch]
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2024-10-17 Add missing datasheets and suppliers
    [audio.kicad_sch, connect.kicad_sch, leds.kicad_sch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]
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2024-10-27 Fix Footprints reported by DRC
2024-10-28 Fix a warning in the notes
    [psu.kicad_sch]
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2024-12-15 Try to fix build
    [pedalboard-hw.kibot.yaml]
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2026-04-14 Add version picker landing page
    - Replace simple redirect with landing page featuring version dropdown
    - CI generates versions.json by scanning gh-pages branch for v* folders
    - Landing page and versions.json deployed to gh-pages root
2026-04-14 Fix version picker: add Go button, include old versions
    - Add placeholder option and Go button so selection always works
    - Include old versions from pedalboard-hw-site with absolute URLs
    - Support both string and object entries in versions.json
2026-04-15 Replace landing page with Hugo site (hugo-kicad-site theme)
    - PaperMod-based multi-page versioned documentation
    - KiCanvas viewer, gallery, downloads, changes pages
    - Old versions preserved in version picker (links to archived site)
    - Downloads and diffs only on tagged releases
    Refs: #16
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2026-04-22 migrate to KiCad 10 and add text variables
    - Update schematic and project files to KiCad 10 format
    - Update symbols from library (solder jumpers, USB connectors)
    - Add GIT_HASH and REVISION text variables to match soundcard project
    [audio.kicad_sch, connect.kicad_sch, leds.kicad_sch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]
2026-04-22 fix USB connector shield pad names for KiCad 10
    - Rename pad 6 to SH in custom USB Micro-B footprint (J9)
    - Update J10 USB-A footprint from library (pad 5 to SH)
    - Resolves DRC shorting/unconnected errors on shield nets
2026-04-22 update PCB footprints from KiCad 10 library
    - Update footprints for USB connectors (J9, J10 shield pads)
    - Update standard footprints (passives, ICs, connectors)
    - Resolves all DRC shorting and unconnected net errors
2026-04-22 fix Y2 crystal courtyard and update remaining footprints
    - Fix malformed courtyard in ABM8-272-T3_ABR footprint (self-intersecting/unclosed)
    - Update Y2 footprint in PCB from library
    - Remove stale DRC exclusion for unresolved_variable
    - ERC: 0 violations, DRC: 0 violations
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2026-04-22 Fix TRS jack 3D model path (KICAD8 → KICAD10, .wrl → .step)
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

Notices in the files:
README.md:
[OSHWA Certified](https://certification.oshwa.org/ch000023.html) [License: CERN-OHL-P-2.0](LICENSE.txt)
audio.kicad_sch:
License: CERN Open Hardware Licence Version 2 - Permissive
